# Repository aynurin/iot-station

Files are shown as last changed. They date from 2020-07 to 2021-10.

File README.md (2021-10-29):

# Nour Eggboard

This is a main board of a low-power battery powered IoT device controller based on ESP8266 (ESP-WROOM-02) that drives peripheral devices on I2C bus.

Currenly the project is under development and you can help in the following way:

* Suggest new features and report bugs
* Submit pull requests
* Help fund the development by [donating via PayPal](https://www.paypal.com/donate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)

## LICENSE

Currently this project is licensed as  [GNU AGPLv3](./LICENSE). This is intended to be changed to Apache or MIT when I get a better feel of the project and see how it moves forward. I would accept suggestions of a qualified lawyer as I need help figuring out how to move forward.

## How is this helpful

Most prototyping boards are exactly what they say - designed for prototyping and difficult to apply in a production device or if you are a hardcore hobbyist. Unlike those projects, the Eggboard is intended to be a final solution that lets you hook your peripherals to an I2C bus and enjoy a low-power battery operation, wireless charging, and WiFi connectivity out of the box.

Features:

* WiFi capability via ESP8266
* Own I2C port that allows I2C communication, sleep power line, ability to operate when host sleeps, and a host wakeup channel
* Customizable (via resistance change) sleep timer that drives the host and all of the peripherals
* Battery operation
* Wireless and USB-C charging
* USB-C programming via esptool or Arduino IDE (and other compatible IDEs and methods)

## Nour Egg Plant station

The example implementation is a Nour Egg plant ecosystem controller that is under development. This device is going to be commercially available for purchase in 2022 along with free downloadable app and a cloud-based analytics platform.

Key features of the Nour Egg:

* Monitor air quality, soil moisture, and lighting conditions of your home plant
* Low-power operation that runs for months on a single charge, and wireless charging
* WiFi connectivity to report statistics to the cloud and Nour Egg app
* Appealing look and feel in a nice shell and beautiful RGB light indicators

Implemented peripherals:

* Soil moisture sensor based on capacitance sensing using a coplanar capacitor probe
* Air quality sensor
* Light sensor
* LED indicators board driving 18 leds or 6 RGB leds

## Roadmap

The versioning works by bird names, e.g. see [WhatBird.com NA Birds by Size](https://www.whatbird.com/browse/attribute/birds_na_147/51/Size/):

| Milestone | Release Date | Focus |
|---|---|---|
| [Pine Siskin](https://github.com/aynurin/iot-station/milestone/1) | September 2021 | Hardware design |
| [Pygmy Nuthatch](https://github.com/aynurin/iot-station/milestone/2) | December 2021 | PoC Cloud and App |
| [Winter Wren](https://github.com/aynurin/iot-station/milestone/3) | March 2022 | Production feasible enclosure |
| [Hutton's Vireo](https://github.com/aynurin/iot-station/milestone/4) | June 2022 | Production feasible hardware, test board production |
.

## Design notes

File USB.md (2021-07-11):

|| CP2102N Pin || Description || Manual Section ||
|---|---|---|
| RTS (O) | Ready to Send, Active Low, CP2102N shows that it's ready to receive data | 4.3.7 |
| CTS (I) | Clear to Send, Active Low, External device tells CP2102N that it's ready to receive data | 4.3.7 |
| DSR (I) | Data Set Ready, Active Low | 4.3.11 |
| DTR (O) | Data Terminal Ready, Active Low (May toggle when opening a COM port on some OS'es) | 4.3.11 |
| DCD (I) | Data Carreir Detect, Active Low | 4.3.11 |
| RI (I) | Ring Indicator, Active Low | 4.3.11 |

|| ESP8266 Pin || Description || Manual Section ||
|---|---|---|
| RST | External reset, active low | 0a-esp8266ex_datasheet_en Pin Definitions |
| GPIO0 | UART Download - pull down, Flash boot - floating or pull up | esp8266_quick_start_guide_en #5 |

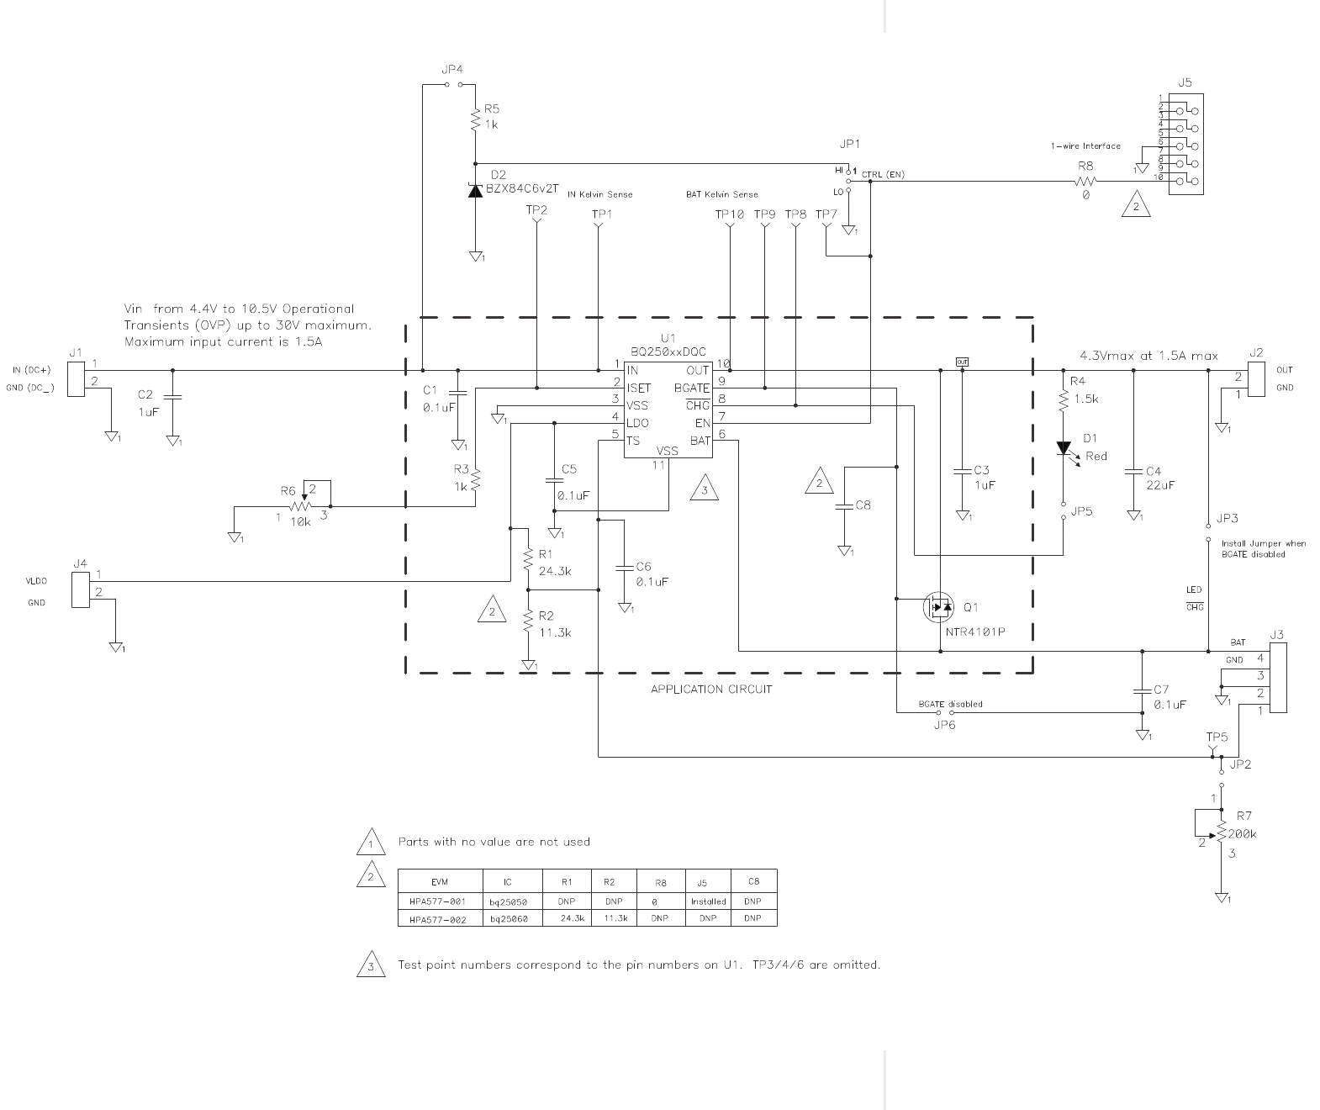
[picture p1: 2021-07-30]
datasheets/bq25050 evl schematics.png

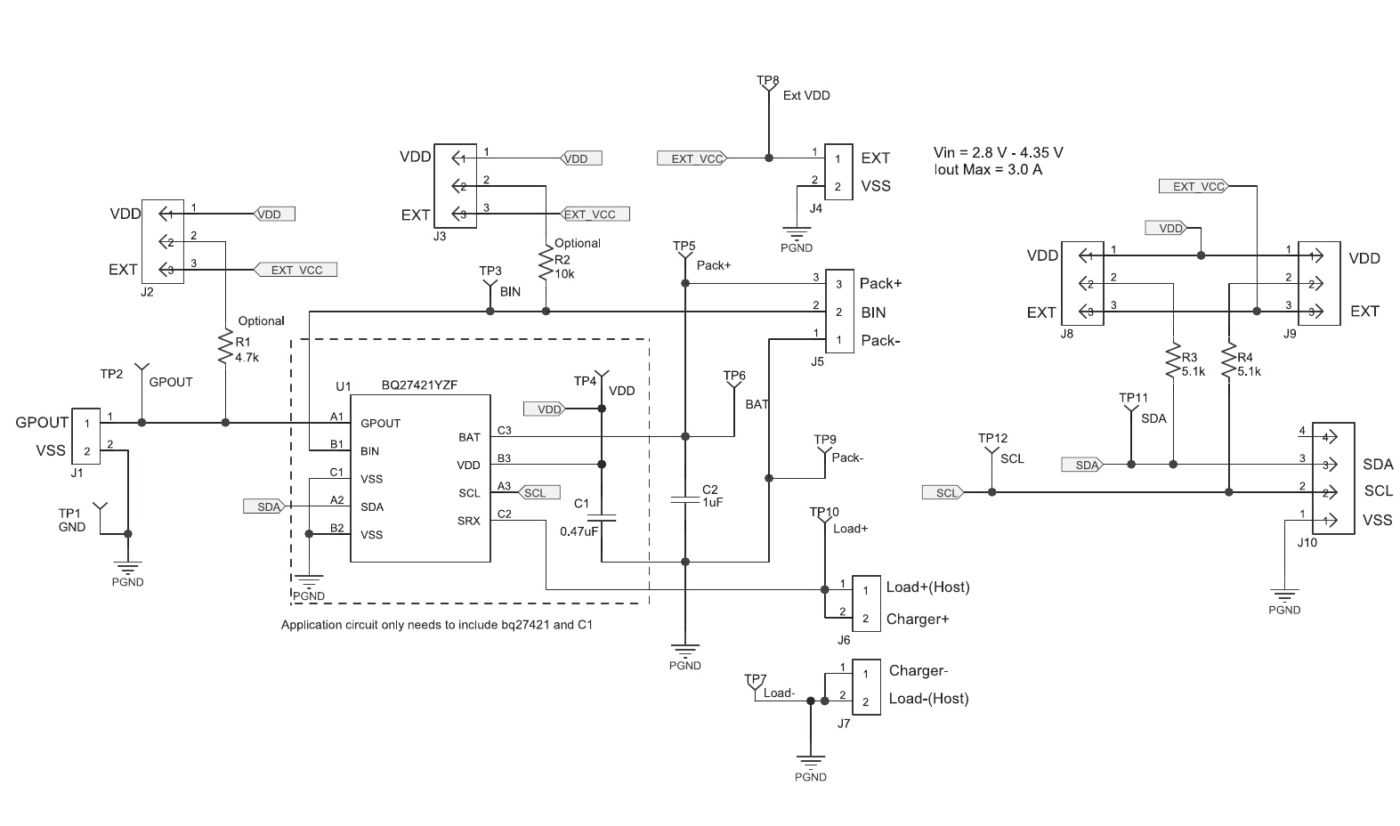
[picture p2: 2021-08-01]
datasheets/bq27421-g1-example-schematics.png

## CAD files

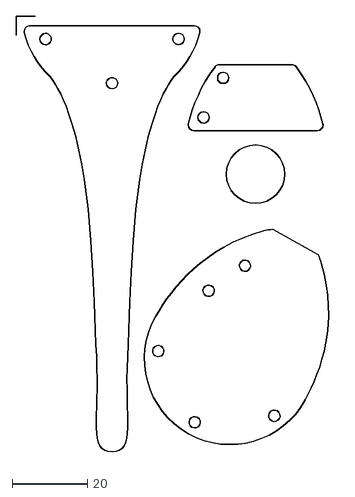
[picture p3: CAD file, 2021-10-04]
assets/board_edge_cuts.dxf
85.6 x 116.9

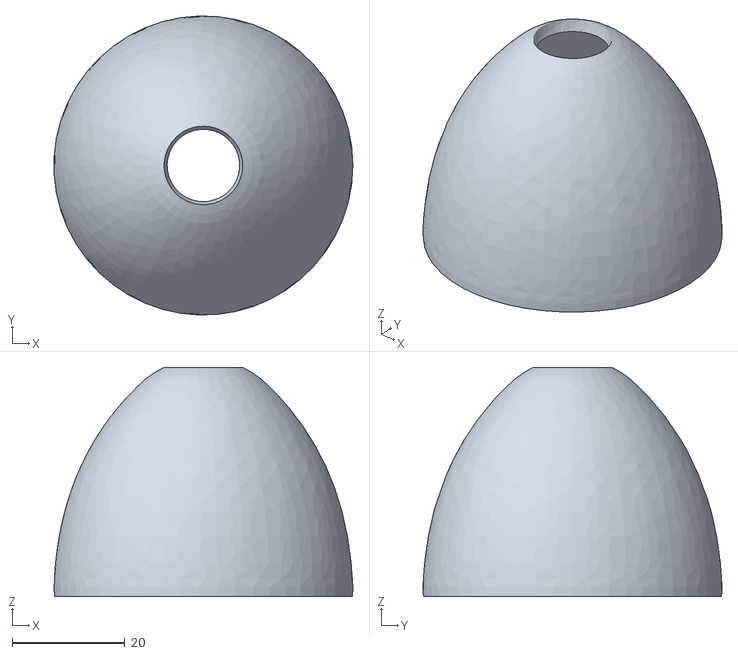
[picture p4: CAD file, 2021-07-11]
assets/enclosure-top.stl
53.1 x 53.1 x 40.7

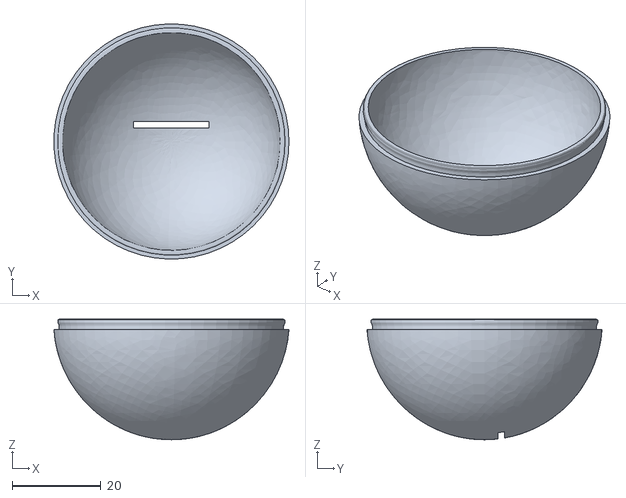
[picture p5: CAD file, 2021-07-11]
assets/enclosure-bottom.stl
52.9 x 52.9 x 27.1

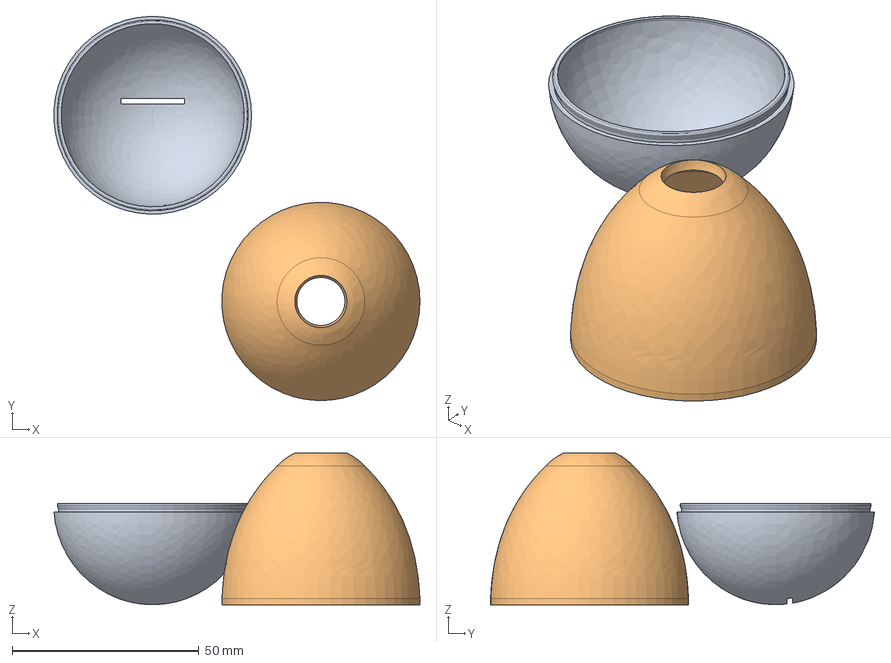
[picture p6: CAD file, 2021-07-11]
assets/enclosure_freecad.FCStd
98.0 x 102.9 x 40.7 mm
Cut001 (Solid)
Cut (Solid)

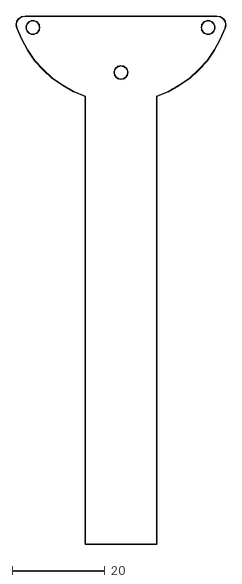
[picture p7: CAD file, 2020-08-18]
assets/moisture_edge_cuts.dxf
45.1 x 113.7

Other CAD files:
assets/enclosure.blend

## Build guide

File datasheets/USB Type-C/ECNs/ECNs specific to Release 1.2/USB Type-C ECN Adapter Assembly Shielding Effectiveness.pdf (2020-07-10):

# USB Type-C ENGINEERING CHANGE NOTICE

USB Implementers Forum | Form 20140811-ECN | Page: 1

# Title: Adapter Assembly Shielding Effectiveness Applied to: USB Type-C Cable and Connector Specification Release 1.2, March 25th, 2016

Brief description of the functional changes proposed:
The change proposed to the specification is the addition of a shielding effectiveness requirement for USB Type-C to USB 3.1 Standard-A Receptacle Adapter Assemblies.

Benefits as a result of the proposed changes:
As the result of this change, well designed adaptor assemblies can be differentiated from poorly-designed adaptor assemblies by comparison against the shielding effectiveness specification.

An assessment of the impact to the existing revision and systems that currently conform to the USB specification:
There may be several USB Type-C to USB 3.1 Standard-A Receptacle Adapter Assemblies that have poor cable shielding and do not meet the shielding effectiveness specification.

An analysis of the hardware implications:
N/A

An analysis of the software implications:
N/A

An analysis of the compliance testing implications:
Measurement was done to evaluate the proposed change using compliance test fixture.

# Actual Change Requested

## (a). Section 3.7.6, Page 97 From Figure 3-56

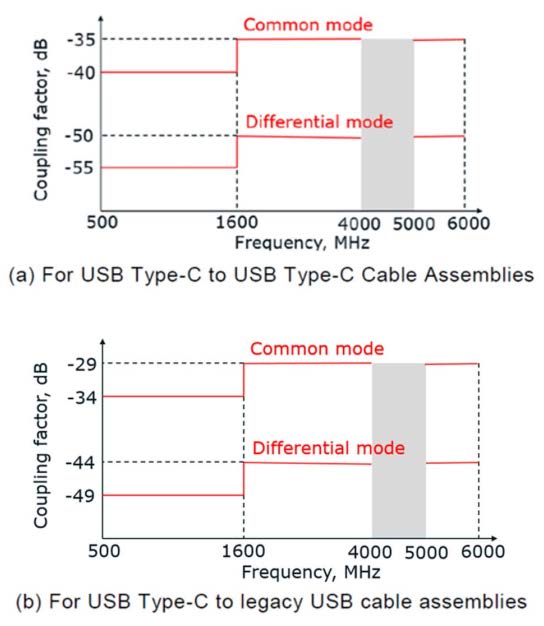
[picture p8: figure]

## To Figure 3-56:

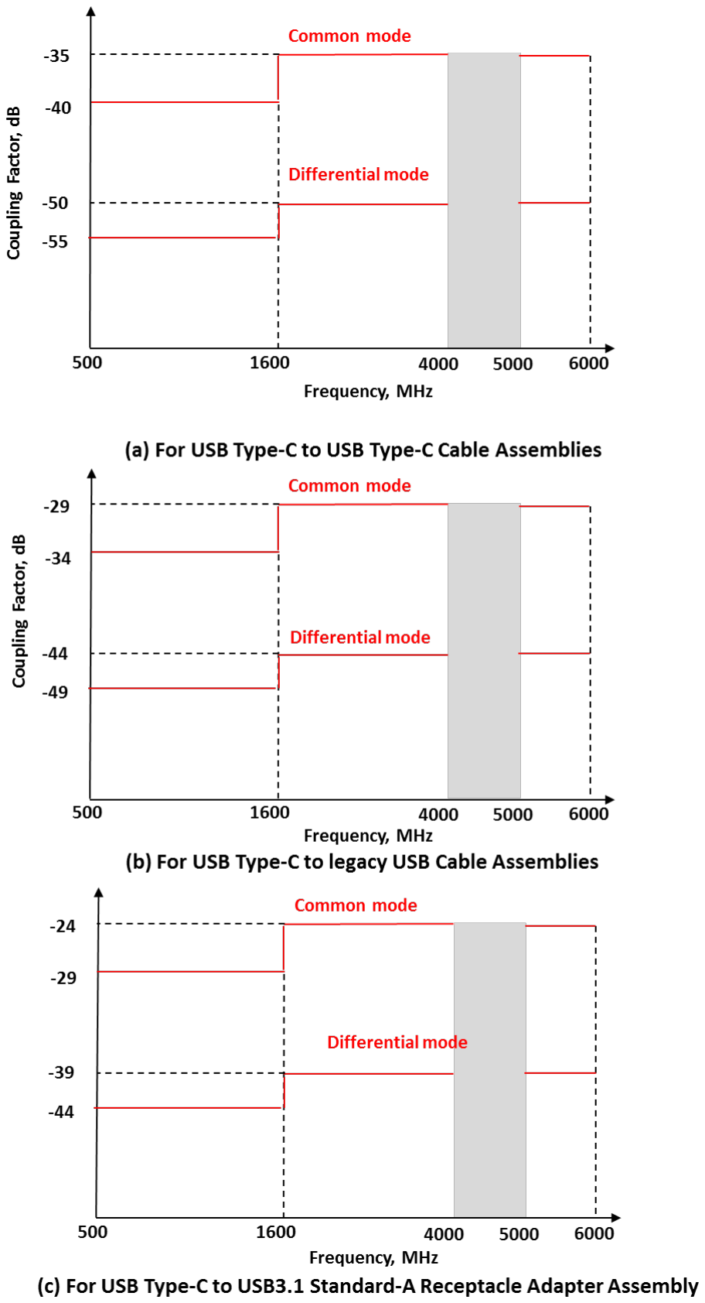
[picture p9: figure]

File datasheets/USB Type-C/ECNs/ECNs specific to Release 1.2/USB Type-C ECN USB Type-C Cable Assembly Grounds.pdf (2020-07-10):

USB Type-C ENGINEERING CHANGE NOTICE

USB Implementers Forum | Form 12022008 | Page: | 1

Title: USB Type-C Cable Assembly Grounding
Applied to: USB Type-C Specification Release 1.2

Brief description of the functional changes proposed:
This ECN requires that all grounds and shields are made common within the standard USB Type-C and USB Type-C to legacy cable assemblies.

Benefits as a result of the proposed changes:
Currently it is allowable to isolate shell and signal grounds within a USB Type-C cable assembly. Cable assemblies with common grounds and isolated grounds require different compliance test methods/fixtures for IR drop measurement. This adds complexity and the potential for failure escapes. Finished product testing should also be tested with both types of ground connection cables to ensure compliance with product emissions.

An assessment of the impact to the existing revision and systems that currently conform to the USB specification:
No impact to existing systems.

An analysis of the hardware implications:
Cable assembly suppliers continue to have flexibility in design, construction, and materials to meet the IR drop spec. However, the ECN unifies the measured path by mandating that if separate ground paths are present that they be made common. This also eliminates the need for emissions testing at the product level using both isolated shield and grounded shield cable assemblies.

An analysis of the software implications:
NA

An analysis of the compliance testing implications:
No change to current compliance testing requirements. Reduces chance of failure escapes.

USB Implementers Forum | Form 12022008 | Page: | 2

Actual Change Requested

From Text (and location): Section 3.4.1, Table 3-10

Table 3-1 USB Full-Featured Type-C Standard Cable Assembly Wiring

USB Type-C Plug #1 | Wire | USB Type-C Plug #2
Pin | Signal Name | Wire Number | Signal Name | Pin | Signal Name
A1, B1, A12, B12 | GND | 1 [16] | GND_PWRrt1 [GND_PWRrt2] | A1, B1, A12, B12 | GND
A4, B4, A9, B9 | VBUS | 2 [17] | PWR_VBUS1 [PWR_VBUS2] | A4, B4, A9, B9 | VBUS
A5 | CC | 3 | CC | A5 | CC
B5 | VCONN | 18 | PWR_VCONN (See Section 4.9) | B5 | VCONN
A6 | Dp1 | 4 | UTP_Dp | A6 | Dp1
A7 | Dn1 | 5 | UTP_Dn | A7 | Dn1
A2 | SSTXp1 | 6 | SDPp1 | B11 | SSRXp1
A3 | SSTXn1 | 7 | SDPn1 | B10 | SSRXn1
B11 | SSRXp1 | 8 | SDPp2 | A2 | SSTXp1
B10 | SSRXn1 | 9 | SDPn2 | A3 | SSTXn1
B2 | SSTXp2 | 10 | SDPp3 | A11 | SSRXp2
B3 | SSTXn2 | 11 | SDPn3 | A10 | SSRXn2
A11 | SSRXp2 | 12 | SDPp4 | B2 | SSTXp2
A10 | SSRXn2 | 13 | SDPn4 | B3 | SSTXn2
A8 | SBU1 | 14 | SBU_A | B8 | SBU2
B8 | SBU2 | 15 | SBU_B | A8 | SBU1
Shell | Shield | Braid | Shield | Shell | Shield
Notes:
1. This table is based on the assumption that coaxial wire construction is used for all SDP’s and there are no drain wires. The shields of the coaxial wires are connected to the ground pins. If shielded twisted pair is used, then drain wires are needed and shall be connected to the GND pins.
2. Pin B5 (VCONN) of the USB Type-C plug shall be used in electronically marked versions of this cable. See Section 4.9.
3. Contacts B6 and B7 should not be present in the USB Type-C plug.
4. All VBUS pins shall be connected together within the USB Type-C plug. A 10 nF bypass capacitor (minimum voltage rating of 30 V) is required for the VBUS pin in the full-featured cable at each end of the cable. The bypass capacitor should be placed as close as possible to the power supply pad.
5. All GND pins shall be connected together within the USB Type-C plug.

USB Implementers Forum | Form 12022008 | Page: | 3

To Text (and location): Section 3.4.1, Table 3-10

Table 3-2 USB Full-Featured Type-C Standard Cable Assembly Wiring

USB Type-C Plug #1 | Wire | USB Type-C Plug #2
Pin | Signal Name | Wire Number | Signal Name | Pin | Signal Name
A1, B1, A12, B12 | GND | 1 [16] | GND_PWRrt1 [GND_PWRrt2] | A1, B1, A12, B12 | GND
A4, B4, A9, B9 | VBUS | 2 [17] | PWR_VBUS1 [PWR_VBUS2] | A4, B4, A9, B9 | VBUS
A5 | CC | 3 | CC | A5 | CC
B5 | VCONN | 18 | PWR_VCONN (See Section 4.9) | B5 | VCONN
A6 | Dp1 | 4 | UTP_Dp | A6 | Dp1
A7 | Dn1 | 5 | UTP_Dn | A7 | Dn1
A2 | SSTXp1 | 6 | SDPp1 | B11 | SSRXp1
A3 | SSTXn1 | 7 | SDPn1 | B10 | SSRXn1
B11 | SSRXp1 | 8 | SDPp2 | A2 | SSTXp1
B10 | SSRXn1 | 9 | SDPn2 | A3 | SSTXn1
B2 | SSTXp2 | 10 | SDPp3 | A11 | SSRXp2
B3 | SSTXn2 | 11 | SDPn3 | A10 | SSRXn2
A11 | SSRXp2 | 12 | SDPp4 | B2 | SSTXp2
A10 | SSRXn2 | 13 | SDPn4 | B3 | SSTXn2
A8 | SBU1 | 14 | SBU_A | B8 | SBU2
B8 | SBU2 | 15 | SBU_B | A8 | SBU1
Shell | Shield | Outer shield | Shield | Shell | Shield

Notes:

1. This table is based on the assumption that coaxial wire construction is used for all SDP’s and there are no drain wires. The shields of the coaxial wires are connected to the ground pins. If shielded twisted pair is used, then drain wires are needed and shall be connected to the GND pins.
2. Pin B5 (VCONN) of the USB Type-C plug shall be used in electronically marked versions of this cable. See Section 4.9.
3. Contacts B6 and B7 should not be present in the USB Type-C plug.
4. All VBUS pins shall be connected together within the USB Type-C plug. A 10 nF bypass capacitor (minimum voltage rating of 30 V) is required for the VBUS pin in the full-featured cable at each end of the cable. The bypass capacitor should be placed as close as possible to the power supply pad.
5. All GND pins shall be connected together within the USB Type-C plug.
6. Shield and GND shall be connected within the USB Type-C plug on both ends of the cable assembly.

USB Implementers Forum | Form 12022008 | Page: | 4

Actual Change Requested

From Text (and location): Section 3.4.2, Table 3-11

Table 3-3 USB 2.0 Type-C Standard Cable Assembly Wiring

USB Type-C Plug #1 | Wire | USB Type-C Plug #2
Pin | Signal Name | Wire Number | Signal Name | Pin | Signal Name
A1, B1, A12, B12 | GND | 1 | GND_PWRrt1 | A1, B1, A12, B12 | GND
A4, B4, A9, B9 | VBUS | 2 | PWR_VBUS1 | A4, B4, A9, B9 | VBUS
A5 | CC | 3 | CC | A5 | CC
B5 | VCONN | 18 | PWR_VCONN (See Section 4.9) | B5 | VCONN
A6 | Dp1 | 4 | UTP_Dp | A6 | Dp1
A7 | Dn1 | 5 | UTP_Dn | A7 | Dn1
Shell | Shield | Braid | Shield | Shell | Shield
Notes:
1. Pin B5 (VCONN) of the USB Type-C plug shall be used in electronically marked versions of this cable. See Section 4.9.
2. Contacts B6 and B7 should not be present in the USB Type-C plug.
3. All VBUS pins shall be connected together within the USB Type-C plug. A bypass capacitor is not required for the VBUS pin in the USB 2.0 Type-C cable.
4. All GND pins shall be connected together within the USB Type-C plug.
5. All USB Type-C plug pins that are not listed in this table shall be open (not connected).

To Text (and location): Section 3.4.2, Table 3-11

USB Implementers Forum | Form 12022008 | Page: | 5

Table 3-4 USB 2.0 Type-C Standard Cable Assembly Wiring

USB Type-C Plug #1 | Wire | USB Type-C Plug #2
Pin | Signal Name | Wire Number | Signal Name | Pin | Signal Name
A1, B1, A12, B12 | GND | 1 | GND_PWRrt1 | A1, B1, A12, B12 | GND
A4, B4, A9, B9 | VBUS | 2 | PWR_VBUS1 | A4, B4, A9, B9 | VBUS
A5 | CC | 3 | CC | A5 | CC
B5 | VCONN | 18 | PWR_VCONN (See Section 4.9) | B5 | VCONN
A6 | Dp1 | 4 | UTP_Dp | A6 | Dp1
A7 | Dn1 | 5 | UTP_Dn | A7 | Dn1
Shell | Shield | Outer shield | Shield | Shell | Shield

Notes:

1. Pin B5 (VCONN) of the USB Type-C plug shall be used in electronically marked versions of this cable. See Section 4.9.
2. Contacts B6 and B7 should not be present in the USB Type-C plug.
3. All VBUS pins shall be connected together within the USB Type-C plug. A bypass capacitor is not required for the VBUS pin in the USB 2.0 Type-C cable.
4. All GND pins shall be connected together within the USB Type-C plug.
5. All USB Type-C plug pins that are not listed in this table shall be open (not connected).
6. Shield and GND grounds shall be connected within the USB Type-C plug on both ends of the cable assembly.

USB Implementers Forum | Form 12022008 | Page: | 6

Actual Change Requested

From Text (and location): Section 3.5.1, Table 3-12

Table 3-5 USB Type-C to USB 3.1 Standard-A Cable Assembly Wiring

USB Type-C Plug | Wire | USB 3.1 Standard-A plug
Pin | Signal Name | Wire Number | Signal Name | Pin | Signal Name
A1, B1, A12, B12 | GND | 1 7, 10 | GND_PWRrt1 SDP1_Drain, SDP2_Drain | 4 7 | GND GND_DRAIN
A4, B4, A9, B9 | VBUS | 2 | PWR_VBUS1 | 1 | VBUS
A5 | CC
B5 | VCONN
A6 | Dp1 | 3 | UTP_Dp | 3 | D+
A7 | Dn1 | 4 | UTP_Dn | 2 | D−
A2 | SSTXp1 | 5 | SDPp1 | 6 | StdA_SSRX+
A3 | SSTXn1 | 6 | SDPn1 | 5 | StdA_SSRX−
B11 | SSRXp1 | 8 | SDPp2 | 9 | StdA_SSTX+
B10 | SSRXn1 | 9 | SDPn2 | 8 | StdA_SSTX−
Shell | Shield | Braid | Shield | Shell | Shield
Notes:
1. This table is based on the assumption that shielded twisted pair is used for all SDP’s and there are drain wires. If coaxial wire construction is used, then no drain wires are present and the shields of the coaxial wires are connected to the ground pins.
2. Pin A5 (CC) of the USB Type-C plug shall be connected to VBUS through a resistor Rp. See Section 4.5.3.2.2 and Table 4-13 for the functional description and value of Rp.
3. Pin B5 (VCONN) of the USB Type-C plug shall be used in electronically marked versions of this cable. See Section 4.9.
4. Contacts B6 and B7 should not be present in the USB Type-C plug.
5. All VBUS pins shall be connected together within the USB Type-C plug. A bypass capacitor is required between the VBUS and ground pins in the USB Type-C plug side of the cable. The bypass capacitor shall be 10nF ± 20% in cables which incorporate a USB Standard-A plug. The bypass capacitor shall be 100pF ± 20% (minimum voltage rating of 30V) in cables which incorporate a USB PD Standard-A plug. The bypass capacitor shall be placed as close as possible to the power supply
pad.
6. All Ground return pins shall be connected together within the USB Type-C plug.
7. All USB Type-C plug pins that are not listed in this table shall be open (not connected).

USB Implementers Forum | Form 12022008 | Page: | 7

To Text (and location): Section 3.5.1, Table 3-12

Table 3-6 USB Type-C to USB 3.1 Standard-A Cable Assembly Wiring

USB Type-C Plug | Wire | USB 3.1 Standard-A plug
Pin | Signal Name | Wire Number | Signal Name | Pin | Signal Name
A1, B1, A12, B12 | GND | 1 7, 10 | GND_PWRrt1 SDP1_Drain, SDP2_Drain | 4 7 | GND GND_DRAIN
A4, B4, A9, B9 | VBUS | 2 | PWR_VBUS1 | 1 | VBUS
A5 | CC
B5 | VCONN
A6 | Dp1 | 3 | UTP_Dp | 3 | D+
A7 | Dn1 | 4 | UTP_Dn | 2 | D−
A2 | SSTXp1 | 5 | SDPp1 | 6 | StdA_SSRX+
A3 | SSTXn1 | 6 | SDPn1 | 5 | StdA_SSRX−
B11 | SSRXp1 | 8 | SDPp2 | 9 | StdA_SSTX+
B10 | SSRXn1 | 9 | SDPn2 | 8 | StdA_SSTX−
Shell | Shield | Outer shield | Shield | Shell | Shield

Notes:

1. This table is based on the assumption that shielded twisted pair is used for all SDP’s and there are drain wires. If coaxial wire construction is used, then no drain wires are present and the shields of the coaxial wires are connected to the ground pins.
2. Pin A5 (CC) of the USB Type-C plug shall be connected to VBUS through a resistor Rp. See Section 4.5.3.2.2 and Table 4-13 for the functional description and value of Rp.
3. Pin B5 (VCONN) of the USB Type-C plug shall be used in electronically marked versions of this cable. See Section 4.9.
4. Contacts B6 and B7 should not be present in the USB Type-C plug.
5. All VBUS pins shall be connected together within the USB Type-C plug. A bypass capacitor is required between the VBUS and ground pins in the USB Type-C plug side of the cable. The bypass capacitor shall be 10nF ± 20% in cables which incorporate a USB Standard-A plug. The bypass capacitor shall be 100pF ± 20% (minimum voltage rating of 30V) in cables which incorporate a USB PD Standard-A plug. The bypass capacitor shall be placed as close as possible to the power supply
pad.
6. All Ground return pins shall be connected together within the USB Type-C plug.
7. Shield and GND grounds shall be connected within the USB Type-C and USB 3.1 Standard-A plugs on both ends of the cable assembly.
8. All USB Type-C plug pins that are not listed in this table shall be open (not connected).

USB Implementers Forum | Form 12022008 | Page: | 8

Actual Change Requested

From Text (and location): Section 3.5.2, Table 3-13

Table 3-7 USB Type-C to USB 2.0 Standard-A Cable Assembly Wiring

USB Type-C Plug | Wire | USB 2.0 Standard-A plug
Pin | Signal Name | Wire Number | Signal Name | Pin | Signal Name
A1, B1, A12, B12 | GND | 1 | GND_PWRrt1 | 4 | GND
A4, B4, A9, B9 | VBUS | 2 | PWR_VBUS1 | 1 | VBUS
A5 | CC
B5 | VCONN
A6 | Dp1 | 3 | UTP_Dp | 3 | D+
A7 | Dn1 | 4 | UTP_Dn | 2 | D−
Shell | Shield | Braid | Shield | Shell | Shield
Notes:
1. Pin A5 (CC) of the USB Type-C plug shall be connected to VBUS through a resistor Rp. See Section 4.5.3.2.2 and Table 4-13 for the functional description and value of Rp.
2. Pin B5 (VCONN) of the USB Type-C plug shall be used in electronically marked versions of this cable. See Section 4.9.
3. Contacts B6 and B7 should not be present in the USB Type-C plug.
4. All VBUS pins shall be connected together within the USB Type-C plug. Bypass capacitors are not required for the VBUS pins in this cable.
5. All Ground return pins shall be connected together within the USB Type-C plug.
6. All USB Type-C plug pins that are not listed in this table shall be open (not connected).

USB Implementers Forum | Form 12022008 | Page: | 9

To Text (and location): Section 3.5.2, Table 3-13

Table 3-8 USB Type-C to USB 2.0 Standard-A Cable Assembly Wiring

USB Type-C Plug | Wire | USB 2.0 Standard-A plug
Pin | Signal Name | Wire Number | Signal Name | Pin | Signal Name
A1, B1, A12, B12 | GND | 1 | GND_PWRrt1 | 4 | GND
A4, B4, A9, B9 | VBUS | 2 | PWR_VBUS1 | 1 | VBUS
A5 | CC
B5 | VCONN
A6 | Dp1 | 3 | UTP_Dp | 3 | D+
A7 | Dn1 | 4 | UTP_Dn | 2 | D−
Shell | Shield | Outer shield | Shield | Shell | Shield

Notes:

1. Pin A5 (CC) of the USB Type-C plug shall be connected to VBUS through a resistor Rp. See Section 4.5.3.2.2 and Table 4-13 for the functional description and value of Rp.
2. Pin B5 (VCONN) of the USB Type-C plug shall be used in electronically marked versions of this cable. See Section 4.9.
3. Contacts B6 and B7 should not be present in the USB Type-C plug.
4. All VBUS pins shall be connected together within the USB Type-C plug. Bypass capacitors are not required for the VBUS pins in this cable.
5. All Ground return pins shall be connected together within the USB Type-C plug.
6. Shield and GND grounds shall be connected within the USB Type-C and USB 2.0 Standard-A plugs on both ends of the cable assembly.
7. All USB Type-C plug pins that are not listed in this table shall be open (not connected).

USB Implementers Forum | Form 12022008 | Page: 10

Actual Change Requested

From Text (and location): Section 3.5.3, Table 3-14

Table 3-9 USB Type-C to USB 3.1 Standard-B Cable Assembly Wiring

USB Type-C Plug | Wire | USB 3.1 Standard-B plug
Pin | Signal Name | Wire Number | Signal Name | Pin | Signal Name
A1, B1, A12, B12 | GND | 1 7, 10 | GND_PWRrt1 SDP1_Drain, SDP2_Drain | 4 7 | GND GND_DRAIN
A4, B4, A9, B9 | VBUS | 2 | PWR_VBUS1 | 1 | VBUS
A5 | CC
B5 | VCONN
A6 | Dp1 | 3 | UTP_Dp | 3 | D+
A7 | Dn1 | 4 | UTP_Dn | 2 | D−
A2 | SSTXp1 | 5 | SDPp1 | 9 | StdB_SSRX+
A3 | SSTXn1 | 6 | SDPn1 | 8 | StdB_SSRX−
B11 | SSRXp1 | 8 | SDPp2 | 6 | StdB_SSTX+
B10 | SSRXn1 | 9 | SDPn2 | 5 | StdB_SSTX−
Shell | Shield | Braid | Shield | Shell | Shield
Notes:
1. Pin A5 (CC) of the USB Type-C plug shall be connected to GND through a resistor Rd. See Section 4.5.3.2.1 and Table 4-14 for the functional description and value of Rd.
2. Pin B5 (VCONN) of the USB Type-C plug shall be used in electronically marked versions of this cable. See Section 4.9.
3. This table is based on the assumption that shielded twisted pair is used for all SDP’s and there are drain wires. If coaxial wire construction is used, then no drain wires are present and the shields of the coaxial wires are connected to the ground pins.
4. Contacts B6 and B7 should not be present in the USB Type-C plug.
5. All VBUS pins shall be connected together within the USB Type-C plug. A bypass capacitor is required between the VBUS and ground pins in the USB Type-C plug side of the cable. The bypass capacitor shall be 10nF ± 20% in cables which incorporate a USB Standard-B plug. The bypass capacitor shall be 100pF ± 20% (minimum voltage rating of 30V) in cables which incorporate a USB PD Standard-B plug. The bypass capacitor shall be placed as close as possible to the power supply
pad.
6. All Ground return pins shall be connected together within the USB Type-C plug.
7. All USB Type-C plug pins that are not listed in this table shall be open (not connected).

To Text (and location): Section 3.5.3, Table 3-14

Table 3-10 USB Type-C to USB 3.1 Standard-B Cable Assembly Wiring

USB Type-C Plug | Wire | USB 3.1 Standard-B plug
Pin | Signal Name | Wire Number | Signal Name | Pin | Signal Name
A1, B1, A12, B12 | GND | 1 7, 10 | GND_PWRrt1 SDP1_Drain, SDP2_Drain | 4 7 | GND GND_DRAIN
A4, B4, A9, B9 | VBUS | 2 | PWR_VBUS1 | 1 | VBUS
A5 | CC
B5 | VCONN
A6 | Dp1 | 3 | UTP_Dp | 3 | D+
A7 | Dn1 | 4 | UTP_Dn | 2 | D−
A2 | SSTXp1 | 5 | SDPp1 | 9 | StdB_SSRX+
A3 | SSTXn1 | 6 | SDPn1 | 8 | StdB_SSRX−
B11 | SSRXp1 | 8 | SDPp2 | 6 | StdB_SSTX+
B10 | SSRXn1 | 9 | SDPn2 | 5 | StdB_SSTX−
Shell | Shield | Outer shield | Shield | Shell | Shield

Notes:

1. Pin A5 (CC) of the USB Type-C plug shall be connected to GND through a resistor Rd. See Section 4.5.3.2.1 and Table 4-14 for the functional description and value of Rd.
2. Pin B5 (VCONN) of the USB Type-C plug shall be used in electronically marked versions of this cable. See Section 4.9.
3. This table is based on the assumption that shielded twisted pair is used for all SDP’s and there are drain wires. If coaxial wire construction is used, then no drain wires are present and the shields of the coaxial wires are connected to the ground pins.
4. Contacts B6 and B7 should not be present in the USB Type-C plug.
5. All VBUS pins shall be connected together within the USB Type-C plug. A bypass capacitor is required between the VBUS and ground pins in the USB Type-C plug side of the cable. The bypass capacitor shall be 10nF ± 20% in cables which incorporate a USB Standard-B plug. The bypass capacitor shall be 100pF ± 20% (minimum voltage rating of 30V) in cables which incorporate a USB PD Standard-B plug. The bypass capacitor shall be placed as close as possible to the power supply
pad.
6. All Ground return pins shall be connected together within the USB Type-C plug.
7. Shield and GND grounds shall be connected within the USB Type-C and USB 3.1 Standard-B plugs on both ends of the cable assembly.
8. All USB Type-C plug pins that are not listed in this table shall be open (not connected).

Actual Change Requested

From Text (and location): Section 3.5.4, Table 3-15

Table 3-11 USB Type-C to USB 2.0 Standard-B Cable Assembly Wiring

USB Type-C Plug | Wire | USB 2.0 Standard-B plug
Pin | Signal Name | Wire Number | Signal Name | Pin | Signal Name
A1, B1, A12, B12 | GND | 1 | GND_PWRrt1 | 4 | GND
A4, B4, A9, B9 | VBUS | 2 | PWR_VBUS1 | 1 | VBUS
A5 | CC
B5 | VCONN
A6 | Dp1 | 3 | UTP_Dp | 3 | D+
A7 | Dn1 | 4 | UTP_Dn | 2 | D−
Shell | Shield | Braid | Shield | Shell | Shield
Notes:
1. Pin A5 (CC) of the USB Type-C plug shall be connected to GND through a resistor Rd. See Section 4.5.3.2.1 and Table 4-14 for the functional description and value of Rd.
2. Pin B5 (VCONN) of the USB Type-C plug shall be used in electronically marked versions of this cable. See Section 4.9.
3. Contacts B6 and B7 should not be present in the USB Type-C plug.
4. All VBUS pins shall be connected together within the USB Type-C plug. Bypass capacitors are not required for the VBUS pins in this cable.
5. All Ground return pins shall be connected together within the USB Type-C plug.
6. All USB Type-C plug pins that are not listed in this table shall be open (not connected).

To Text (and location): Section 3.5.4, Table 3-15

Table 3-12 USB Type-C to USB 2.0 Standard-B Cable Assembly Wiring

USB Type-C Plug | Wire | USB 2.0 Standard-B plug
Pin | Signal Name | Wire Number | Signal Name | Pin | Signal Name
A1, B1, A12, B12 | GND | 1 | GND_PWRrt1 | 4 | GND
A4, B4, A9, B9 | VBUS | 2 | PWR_VBUS1 | 1 | VBUS
A5 | CC
B5 | VCONN
A6 | Dp1 | 3 | UTP_Dp | 3 | D+
A7 | Dn1 | 4 | UTP_Dn | 2 | D−
Shell | Shield | Outer shield | Shield | Shell | Shield

Notes:

1. Pin A5 (CC) of the USB Type-C plug shall be connected to GND through a resistor Rd. See Section 4.5.3.2.1 and Table 4-14 for the functional description and value of Rd.
2. Pin B5 (VCONN) of the USB Type-C plug shall be used in electronically marked versions of this cable. See Section 4.9.
3. Contacts B6 and B7 should not be present in the USB Type-C plug.
4. All VBUS pins shall be connected together within the USB Type-C plug. Bypass capacitors are not required for the VBUS pins in this cable.
5. All Ground return pins shall be connected together within the USB Type-C plug.
6. Shield and GND grounds shall be connected within the USB Type-C and USB 2.0 Standard-B plugs on both ends of the cable assembly.
7. All USB Type-C plug pins that are not listed in this table shall be open (not connected).

Actual Change Requested

From Text (and location): Section 3.5.5, Table 3-16

Table 3-13 USB Type-C to USB 2.0 Mini-B Cable Assembly Wiring

USB Type-C Plug | Wire | USB 2.0 Mini-B plug
Pin | Signal Name | Wire Number | Signal Name | Pin | Signal Name
A1, B1, A12, B12 | GND | 1 | GND_PWRrt1 | 5 | GND
A4, B4, A9, B9 | VBUS | 2 | PWR_VBUS1 | 1 | VBUS
A5 | CC
A6 | Dp1 | 3 | UTP_Dp | 3 | D+
A7 | Dn1 | 4 | UTP_Dn | 2 | D−
| | | | 4 | ID
Shell | Shield | Braid | Shield | Shell | Shield
Notes:
1. Pin A5 of the USB Type-C plug shall be connected to GND through a resistor Rd. See Section 4.5.3.2.1 and Table 4-14 for the functional description and value of Rd.
2. Contacts B6 and B7 should not be present in the USB Type-C plug.
3. All VBUS pins shall be connected together within the USB Type-C plug. Bypass capacitors are not required for the VBUS pins in this cable.
4. All Ground return pins shall be connected together within the USB Type-C plug.
5. Pin 4 (ID) of the USB 2.0 Mini-B plug shall be terminated as defined in the applicable specification for the cable type.
6. All USB Type-C plug pins that are not listed in this table shall be open (not connected).

To Text (and location): Section 3.5.5, Table 3-16

Table 3-14 USB Type-C to USB 2.0 Mini-B Cable Assembly Wiring

USB Type-C Plug | Wire | USB 2.0 Mini-B plug
Pin | Signal Name | Wire Number | Signal Name | Pin | Signal Name
A1, B1, A12, B12 | GND | 1 | GND_PWRrt1 | 5 | GND
A4, B4, A9, B9 | VBUS | 2 | PWR_VBUS1 | 1 | VBUS
A5 | CC
A6 | Dp1 | 3 | UTP_Dp | 3 | D+
A7 | Dn1 | 4 | UTP_Dn | 2 | D−
| | | | 4 | ID
Shell | Shield | Outer shield | Shield | Shell | Shield

Notes:

1. Pin A5 of the USB Type-C plug shall be connected to GND through a resistor Rd. See Section 4.5.3.2.1 and Table 4-14 for the functional description and value of Rd.
2. Contacts B6 and B7 should not be present in the USB Type-C plug.
3. All VBUS pins shall be connected together within the USB Type-C plug. Bypass capacitors are not required for the VBUS pins in this cable.
4. All Ground return pins shall be connected together within the USB Type-C plug.
5. Pin 4 (ID) of the USB 2.0 Mini-B plug shall be terminated as defined in the applicable specification for the cable type.
6. Shield and GND grounds shall be connected within the USB Type-C and USB 2.0 Mini-B plugs on both ends of the cable assembly.
7. All USB Type-C plug pins that are not listed in this table shall be open (not connected).

Actual Change Requested

From Text (and location): Section 3.5.6, Table 3-17

Table 3-15 USB Type-C to USB 3.1 Micro-B Cable Assembly Wiring

USB Type-C Plug | Wire | USB 3.1 Micro-B plug
Pin | Signal Name | Wire Number | Signal Name | Pin | Signal Name
A1, B1, A12, B12 | GND | 1 7, 10 | GND_PWRrt1 SDP1_Drain, SDP2_Drain | 5 8 | GND GND_DRAIN
A4, B4, A9, B9 | VBUS | 2 | PWR_VBUS1 | 1 | VBUS
A5 | CC
B5 | VCONN
A6 | Dp1 | 3 | UTP_Dp | 3 | D+
A7 | Dn1 | 4 | UTP_Dn | 2 | D−
A2 | SSTXp1 | 5 | SDPp1 | 10 | MicB_SSRX+
A3 | SSTXn1 | 6 | SDPn1 | 9 | MicB_SSRX−
B11 | SSRXp1 | 8 | SDPp2 | 7 | MicB_SSTX+
B10 | SSRXn1 | 9 | SDPn2 | 6 | MicB_SSTX−
| | | | 4 | ID
Shell | Shield | Braid | Shield | Shell | Shield
Notes:
1. Pin A5 (CC) of the USB Type-C plug shall be connected to GND through a resistor Rd. See Section 4.5.3.2.1 and Table 4-14 for the functional description and value of Rd.
2. Pin B5 (VCONN) of the USB Type-C plug shall be used in electronically marked versions of this cable. See Section 4.9.
3. This table is based on the assumption that shielded twisted pair is used for all SDP’s and there are drain wires. If coaxial wire construction is used, then no drain wires are present and the shields of the coaxial wires are connected to the ground pins.
4. Contacts B6 and B7 should not be present in the USB Type-C plug.
5. All VBUS pins shall be connected together within the USB Type-C plug. A bypass capacitor is required between the VBUS and ground pins in the USB Type-C plug side of the cable. The bypass capacitor shall be 10nF ± 20% in cables which incorporate a USB Micro-B plug. The bypass capacitor shall be 100pF ± 20% (minimum voltage rating of 30V) in cables which incorporate a USB PD Micro-B plug. The bypass capacitor should be placed as close as possible to the power supply
pad.
6. All Ground return pins shall be connected together within the USB Type-C plug.
7. Pin 4 (ID) of the USB 3.1 Micro-B plug shall be terminated as defined in the applicable specification for the cable type.
8. All USB Type-C plug pins that are not listed in this table shall be open (not connected).

To Text (and location): Section 3.5.6, Table 3-17

Table 3-16 USB Type-C to USB 3.1 Micro-B Cable Assembly Wiring

USB Type-C Plug | Wire | USB 3.1 Micro-B plug

Pin | Signal Name | Wire Number | Signal Name | Pin | Signal Name
A1, B1, A12, B12 | GND | 1 7, 10 | GND_PWRrt1 SDP1_Drain, SDP2_Drain | 5 8 | GND GND_DRAIN
A4, B4, A9, B9 | VBUS | 2 | PWR_VBUS1 | 1 | VBUS
A5 | CC
B5 | VCONN
A6 | Dp1 | 3 | UTP_Dp | 3 | D+
A7 | Dn1 | 4 | UTP_Dn | 2 | D−
A2 | SSTXp1 | 5 | SDPp1 | 10 | MicB_SSRX+
A3 | SSTXn1 | 6 | SDPn1 | 9 | MicB_SSRX−
B11 | SSRXp1 | 8 | SDPp2 | 7 | MicB_SSTX+
B10 | SSRXn1 | 9 | SDPn2 | 6 | MicB_SSTX−
| | | | 4 | ID
Shell | Shield | Outer shield | Shield | Shell | Shield

Notes:

1. Pin A5 (CC) of the USB Type-C plug shall be connected to GND through a resistor Rd. See Section 4.5.3.2.1 and Table 4-14 for the functional description and value of Rd.
2. Pin B5 (VCONN) of the USB Type-C plug shall be used in electronically marked versions of this cable. See Section 4.9.
3. This table is based on the assumption that shielded twisted pair is used for all SDP’s and there are drain wires. If coaxial wire construction is used, then no drain wires are present and the shields of the coaxial wires are connected to the ground pins.
4. Contacts B6 and B7 should not be present in the USB Type-C plug.
5. All VBUS pins shall be connected together within the USB Type-C plug. A bypass capacitor is required between the VBUS and ground pins in the USB Type-C plug side of the cable. The bypass capacitor shall be 10nF ± 20% in cables which incorporate a USB Micro-B plug. The bypass capacitor shall be 100pF ± 20% (minimum voltage rating of 30V) in cables which incorporate a USB PD Micro-B plug. The bypass capacitor should be placed as close as possible to the power supply
pad.
6. All Ground return pins shall be connected together within the USB Type-C plug.
7. Shield and GND grounds shall be connected within the USB Type-C and USB 3.1 Micro-B plugs on both ends of the cable assembly.
8. Pin 4 (ID) of the USB 3.1 Micro-B plug shall be terminated as defined in the applicable specification for the cable type.
9. All USB Type-C plug pins that are not listed in this table shall be open (not connected).

Actual Change Requested

From Text (and location): Section 3.5.7, Table 3-18

Table 3-17 USB Type-C to USB 2.0 Micro-B Cable Assembly Wiring

USB Type-C Plug | Wire | USB 2.0 Micro-B plug
Pin | Signal Name | Wire Number | Signal Name | Pin | Signal Name
A1, B1, A12, B12 | GND | 1 | GND_PWRrt1 | 5 | GND
A4, B4, A9, B9 | VBUS | 2 | PWR_VBUS1 | 1 | VBUS
A5 | CC
B5 | VCONN
A6 | Dp1 | 3 | UTP_Dp | 3 | D+
A7 | Dn1 | 4 | UTP_Dn | 2 | D−
| | | | 4 | ID
Shell | Shield | Braid | Shield | Shell | Shield
Notes:
1. Pin A5 (CC) of the USB Type-C plug shall be connected to GND through a resistor Rd. See Section 4.5.3.2.1 and Table 4-14 for the functional description and value of Rd.
2. Pin B5 (VCONN) of the USB Type-C plug shall be used in electronically marked versions of this cable. See Section 4.9.
3. Contacts B6 and B7 should not be present in the USB Type-C plug.
4. All VBUS pins shall be connected together within the USB Type-C plug. Bypass capacitors are not required for the VBUS pins in this cable.
5. All Ground return pins shall be connected together within the USB Type-C plug.
6. Pin 4 (ID) of the USB 2.0 Micro-B plug shall be terminated as defined in the applicable specification for the cable type.
7. All USB Type-C plug pins that are not listed in this table shall be open (not connected).

To Text (and location): Section 3.5.7, Table 3-18

Table 3-18 USB Type-C to USB 2.0 Micro-B Cable Assembly Wiring

USB Type-C Plug | Wire | USB 2.0 Micro-B plug

Pin | Signal Name | Wire Number | Signal Name | Pin | Signal Name
A1, B1, A12, B12 | GND | 1 | GND_PWRrt1 | 5 | GND
A4, B4, A9, B9 | VBUS | 2 | PWR_VBUS1 | 1 | VBUS
A5 | CC
B5 | VCONN
A6 | Dp1 | 3 | UTP_Dp | 3 | D+
A7 | Dn1 | 4 | UTP_Dn | 2 | D−
| | | | 4 | ID
Shell | Shield | Outer shield | Shield | Shell | Shield

Notes:

1. Pin A5 (CC) of the USB Type-C plug shall be connected to GND through a resistor Rd. See Section 4.5.3.2.1 and Table 4-14 for the functional description and value of Rd.
2. Pin B5 (VCONN) of the USB Type-C plug shall be used in electronically marked versions of this cable. See Section 4.9.
3. Contacts B6 and B7 should not be present in the USB Type-C plug.
4. All VBUS pins shall be connected together within the USB Type-C plug. Bypass capacitors are not required for the VBUS pins in this cable.
5. All Ground return pins shall be connected together within the USB Type-C plug.
6. Shield and GND grounds shall be connected within the USB Type-C and USB 2.0 Micro-B plugs on both ends of the cable assembly.
7. Pin 4 (ID) of the USB 2.0 Micro-B plug shall be terminated as defined in the applicable specification for the cable type.
8. All USB Type-C plug pins that are not listed in this table shall be open (not connected).

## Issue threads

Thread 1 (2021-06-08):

Wire all components together

aynurin, 2021-06-08:
Create wires and connect all peripherals to the mainboard. Make sure all devices respond.

aynurin, 2021-07-08:
Tested all separately. Wiring together doesn't make sense with the current wires and connectors as they are going to be deprecated.

Closed 2021-08-02.

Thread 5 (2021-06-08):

Battery powered

aynurin, 2021-06-08:
The device (mainboard and all peripherals) will be powered by a battery.

The ideal goals are (in the order of priority):

* Fit in the current enclosure (see enclosure design in [assets](https://github.com/aynurin/iot-station/tree/master/assets))
* Able to work in all normal natural environment conditions (humidity 5-95%, temp -40C-+55C)
* Run for a year on a single full charge.
* Able to work under direct sunlight (up to +125C)

Closed 2021-08-02.

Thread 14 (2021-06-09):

Update schematics

aynurin, 2021-06-09:
- [x] Add WROOM power diode
- [x] Add power regulator and rewire CP2102N for self-powered
- [x] Reduce USB power/tx diodes brightness (significantly)

Closed 2021-08-02.

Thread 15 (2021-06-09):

Debug the sleep group

aynurin, 2021-06-09:
The sleep group should allow:
[] Sleep the device on regular intervals
[] Allow the device to prevent it from sleep
[] Figure out if we have to allow external wake up

Closed 2021-07-23.

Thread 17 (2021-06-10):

Look for different wire-to-board connectors

aynurin, 2021-06-10:
The downside of the current connectors is that they are too bulky and difficult to assemble. It feels like we can do a better job in either or both of these areas.

aynurin, 2021-07-10:
Related to #20. Contact the manufacturer for options.

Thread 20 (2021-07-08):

Research wires for wire-to-board connectors

aynurin, 2021-07-08:
The current wires are too stiff and not reliable. It's also way too difficult to assemble a full wire.

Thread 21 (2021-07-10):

Re-engineer the timer block

aynurin, 2021-07-10:
The current timer block is not valid:
1. We don't control the HIGH time of WAKE_UP, but we need to guarantee that M_DRV is pulled to VDD momentarily and not continuously
2. The DRV is Active HIGH, so it should drive the MOSFET as a NOT gate (at the moment it drives it directly)

- [x] See if this timer is necessary or we could use ESP8266 built-in Deep Sleep (think about how to Deep Sleep the peripherals in this case)
- [x] Fix the WAKE_UP logic
- [x] Fix the DRV logic
- [x] Fact check via creating a sequence diagram for ON/OFF states.

Closed 2021-08-02.

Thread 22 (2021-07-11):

Implement a Reset button

aynurin, 2021-07-11:
Maybe it is helpful to easily reboot the board.

Closed 2021-08-02.

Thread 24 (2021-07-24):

Implement battery charging detection

aynurin, 2021-07-24:
CP2102N can report on how much power the charger can take from the USB port as described in section 4.3.4 of the specification. The charging block needs to be configured to take advantage of this detection.

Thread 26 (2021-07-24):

Software sleep

aynurin, 2021-07-24:
Even though the device hardware will disconnect everything on timer, there are cases when the timer keeps running (e.g., when external power source is connected). In this case, the software needs to avoid bombarding the cloud with data.

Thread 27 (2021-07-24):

Soil moisture sensor sensitivity

aynurin, 2021-07-24:
Configure the Soil Moisture Sensor timer with higher sensitivity. Currently, it reads 187 for 100% moist and 226 for dry (at air humidity = 40%). Need to try and adjust the timer and ref. cap. to produce a wider range of values.

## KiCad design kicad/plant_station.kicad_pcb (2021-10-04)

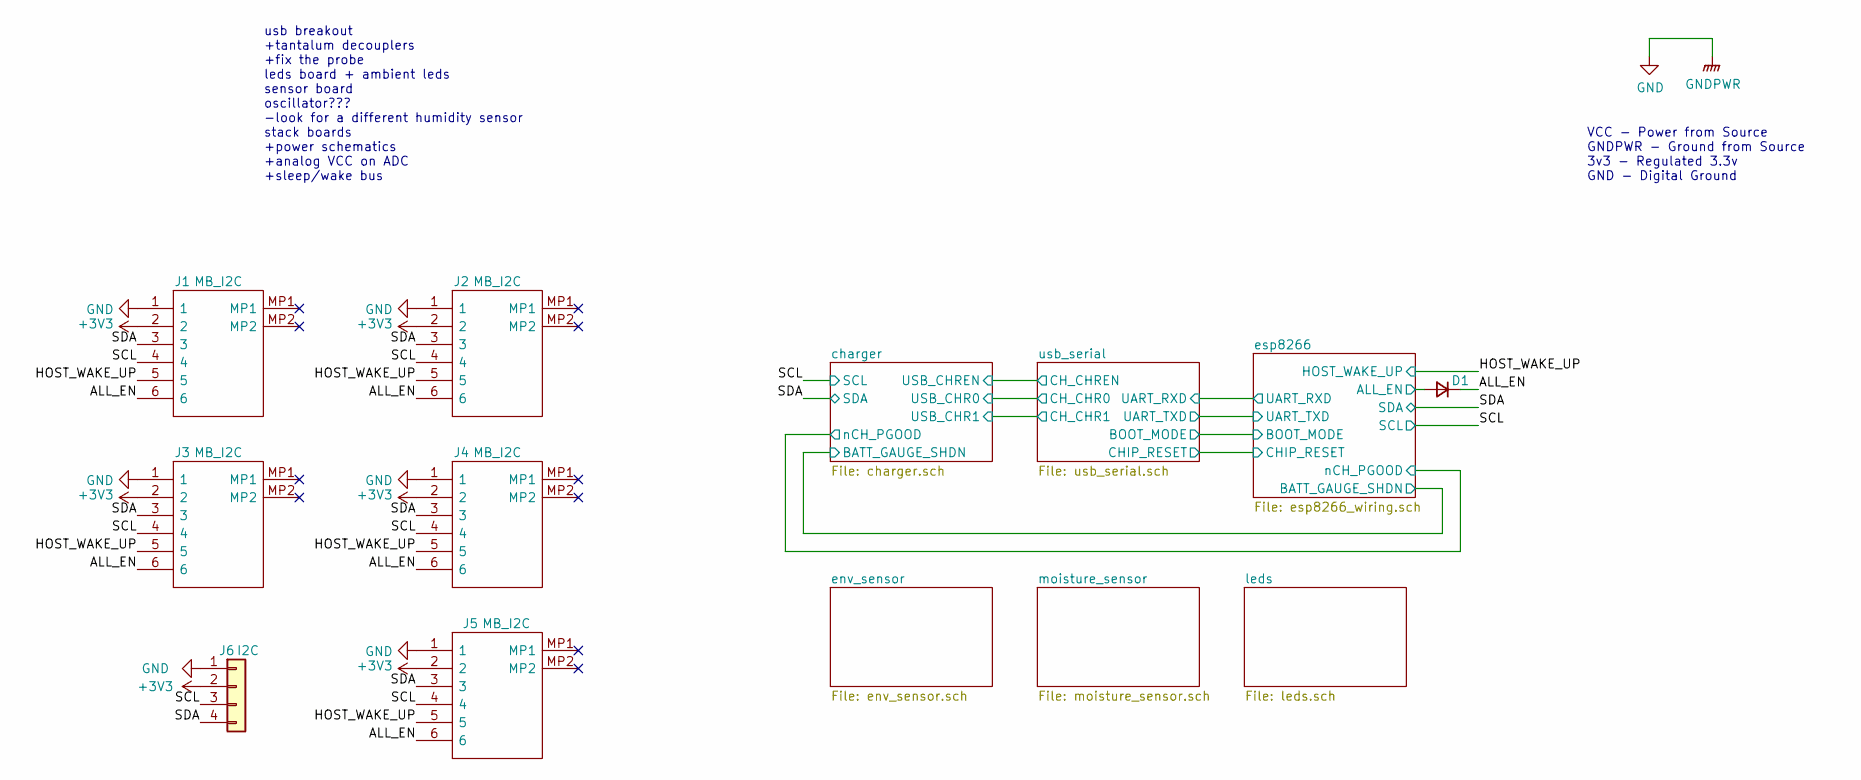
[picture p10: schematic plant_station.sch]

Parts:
D1: LS4148; MELF_SOD_80_3_BZT55B13GS08
J1, J2, J3, J4, J5: MB_I2C; Molex_Conn_SMD_01x06_505567_0671; Manufacturer_Part_Number 505567-0671; Mouser Part Number 538-505567-0671
J6: I2C; PinSocket_1x04_P2.54mm_Vertical

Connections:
/ALL_EN: D1.1 (K), J1.6, J2.6, J3.6, J4.6, J5.6
/HOST_WAKE_UP: J1.5, J2.5, J3.5, J4.5, J5.5; also elsewhere on the board
/SCL: J1.4, J2.4, J3.4, J4.4, J5.4, J6.3; also elsewhere on the board
/SDA: J1.3, J2.3, J3.3, J4.3, J5.3, J6.4; also elsewhere on the board
/esp8266/ALL_EN: D1.2 (A); also elsewhere on the board
GND: J1.1, J2.1, J3.1, J4.1, J5.1, J6.1; also elsewhere on the board

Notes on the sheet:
usb breakout +tantalum decouplers +fix the probe leds board + ambient leds sensor board oscillator??? -look for a different humidity sensor stack boards +power schematics +analog VCC on ADC +sleep/wake bus
VCC - Power from Source GNDPWR - Ground from Source 3v3 - Regulated 3.3v GND - Digital Ground

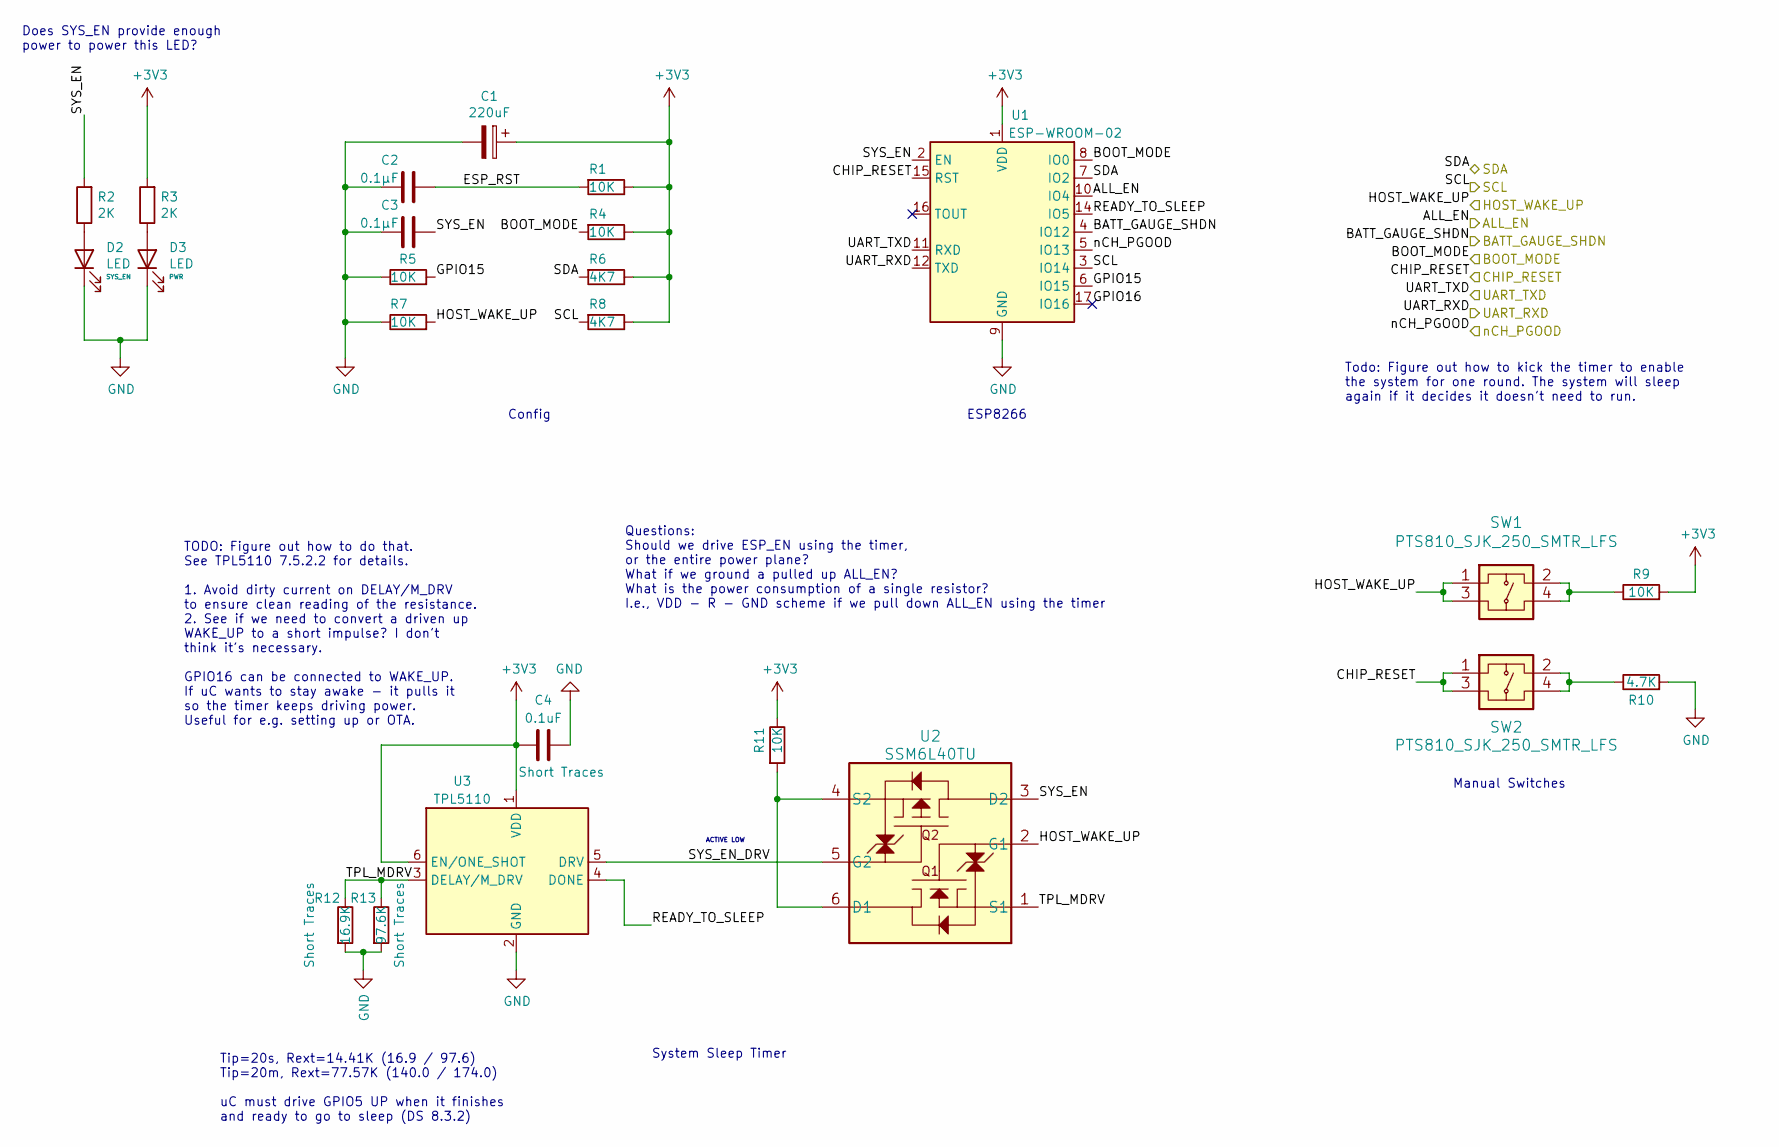
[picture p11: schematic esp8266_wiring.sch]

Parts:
C1: 220uF; CP_EIA-3216-18_Kemet-A
C2, C3: 0.1μF; C_1206_3216Metric
C4: 0.1uF; C_1206_3216Metric
D2, D3: LED; LED_0603_1608Metric
R1, R4, R5, R7, R9, R11: 10K; R_0805_2012Metric
R2, R3: 2K; R_0805_2012Metric
R6, R8: 4K7; R_0805_2012Metric
R10: 4.7K; R_0805_2012Metric
R12: 16.9K; R_0805_2012Metric
R13: 97.6K; R_0805_2012Metric
SW1, SW2: PTS810_SJK_250_SMTR_LFS; PTS810SJK250SMTRLFS
U1: ESP-WROOM-02
U2: SSM6L40TU
U3: TPL5110; SOT-23-6

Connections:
/HOST_WAKE_UP: R7.2, SW1.1, SW1.3, U2.2 (G1); also elsewhere on the board
/SCL: R8.2, U1.3 (IO14); also elsewhere on the board
/SDA: R6.2, U1.7 (IO2); also elsewhere on the board
/charger/BATT_GAUGE_SHDN: U1.4 (IO12); also elsewhere on the board
/charger/nCH_PGOOD: U1.5 (IO13); also elsewhere on the board
/esp8266/ALL_EN: U1.10 (IO4); also elsewhere on the board
/esp8266/BOOT_MODE: R4.2, U1.8 (IO0); also elsewhere on the board
/esp8266/CHIP_RESET: SW2.1, SW2.3, U1.15 (RST); also elsewhere on the board
/esp8266/ESP_RST: C2.2, R1.2
/esp8266/GPIO15: R5.2, U1.6 (IO15)
/esp8266/GPIO16: U1.17 (IO16)
/esp8266/READY_TO_SLEEP: U1.14 (IO5), U3.4 (DONE)
/esp8266/SYS_EN: C3.2, R2.2, U1.2 (EN), U2.3 (D2)
/esp8266/SYS_EN_DRV: U2.5 (G2), U3.5 (DRV)
/esp8266/TPL_MDRV: R12.1, R13.1, U2.1 (S1), U3.3 (DELAY/M_DRV)
/esp8266/UART_RXD: U1.12 (TXD); also elsewhere on the board
/esp8266/UART_TXD: U1.11 (RXD); also elsewhere on the board
GND: C1.2, C2.1, C3.1, C4.1, D2.1 (K), D3.1 (K), R5.1, R7.1, R10.2, R12.2, R13.2, U1.9 (GND), U1.13 (GND), U1.18 (GND), U1.19 (GND), U3.2 (GND); also elsewhere on the board
unnamed: D2.2 (A), R2.1
unnamed: D3.2 (A), R3.1
unnamed: R9.1, SW1.2, SW1.4
unnamed: R10.1, SW2.2, SW2.4
unnamed: R11.2, U2.4 (S2), U2.6 (D1)

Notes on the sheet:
Config
System Sleep Timer
Tip=20s, Rext=14.41K (16.9 / 97.6) Tip=20m, Rext=77.57K (140.0 / 174.0) uC must drive GPIO5 UP when it finishes and ready to go to sleep (DS 8.3.2)
TODO: Figure out how to do that. See TPL5110 7.5.2.2 for details. 1. Avoid dirty current on DELAY/M_DRV to ensure clean reading of the resistance. 2. See if we need to convert a driven up WAKE_UP to a short impulse? I don't think it's necessary. GPIO16 can be connected to WAKE_UP. If uC wants to st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
Questions: Should we drive ESP_EN using the timer, or the entire power plane? What if we ground a pulled up ALL_EN? What is the power consumption of a single resistor? I.e., VDD - R - GND scheme if we pull down ALL_EN using the timer
ACTIVE LOW
ESP8266
Does SYS_EN provide enough power to power this LED?
Manual Switches
Todo: Figure out how to kick the timer to enable the system for one round. The system will sleep again if it decides it doesn't need to run.

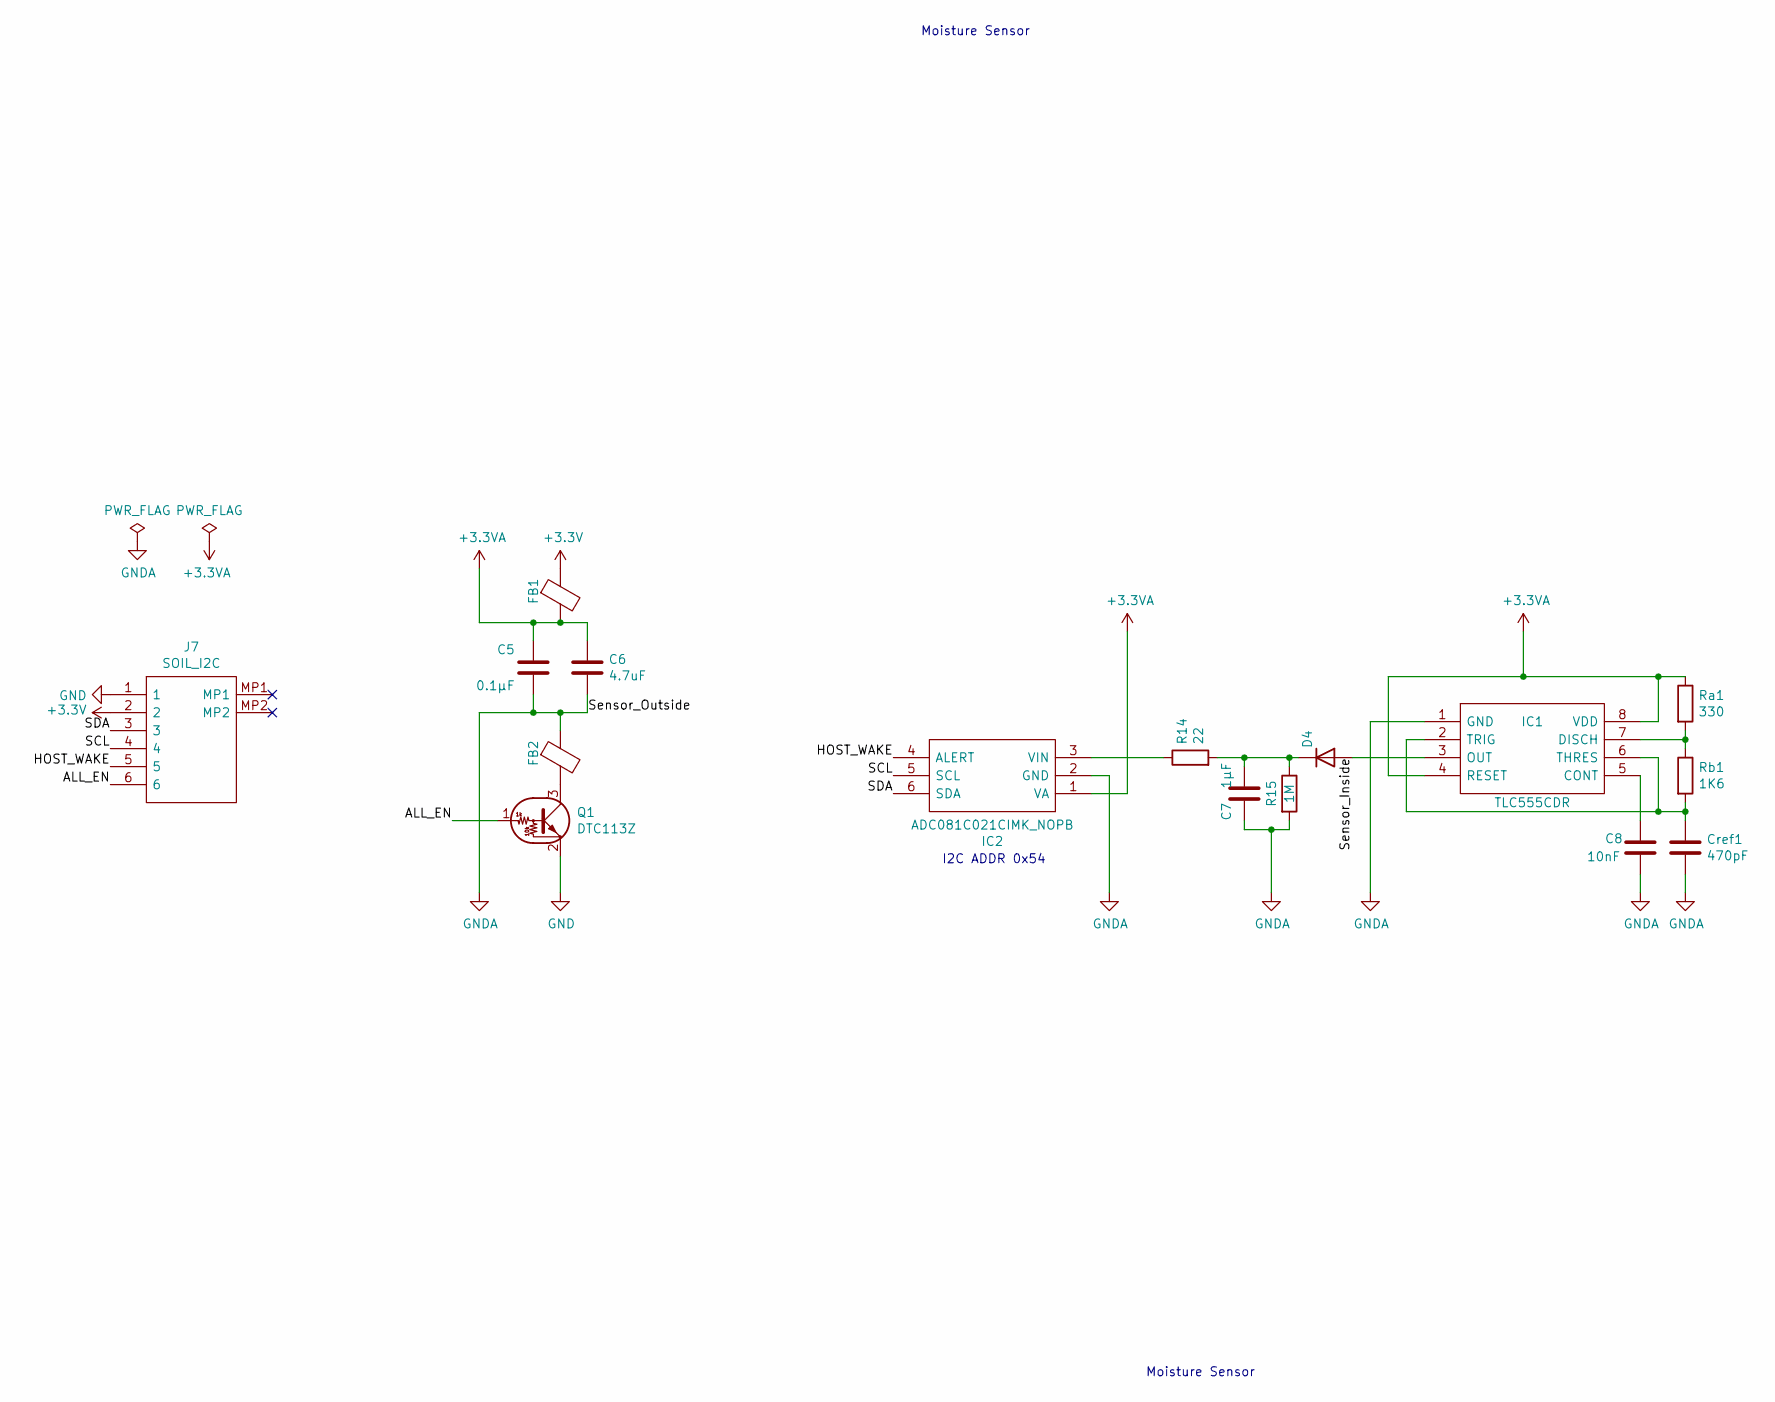
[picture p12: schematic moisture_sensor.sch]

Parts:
C5: 0.1μF; C_1206_3216Metric
C6: 4.7uF; C_1206_3216Metric
C7: 1μF; C_1206_3216Metric
C8: 10nF; C_1206_3216Metric
Cref1: 470pF; C_1206_3216Metric
D4: LS4148; MELF_SOD_80_3_BZT55B13GS08
FB1, FB2: BLM21AG601SZ1D; Ferrite_Bead_0805_BLM21
IC1: TLC555CDR; SOIC127P600X175-8N; Mouser Part Number 595-TLC555CDR
IC2: ADC081C021CIMK_NOPB; SOT95P280X110-6N; Mouser Part Number 926-AD081C021CIMKNPB
J7: SOIL_I2C; Molex_Conn_SMD_01x06_505567_0671; Manufacturer_Part_Number 505567-0671; Mouser Part Number 538-505567-0671
Q1: DTC113Z; DTC113ZEBTL
R14: 22; R_0805_2012Metric
R15: 1M; R_1206_3216Metric
Ra1: 330; R_0805_2012Metric
Rb1: 1K6; R_1206_3216Metric

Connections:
+3.3VA: C5.2, C6.1, FB1.2, IC1.4 (RESET), IC1.8 (VDD), IC2.1 (VA), Ra1.1
/moisture_sensor/ALL_EN: J7.6, Q1.1 (B)
/moisture_sensor/HOST_WAKE: IC2.4 (ALERT), J7.5
/moisture_sensor/SCL: IC2.5 (SCL), J7.4
/moisture_sensor/SDA: IC2.6 (SDA), J7.3
/moisture_sensor/Sensor_Inside: D4.2 (A), IC1.3 (OUT)
GND: J7.1, Q1.2 (E); also elsewhere on the board
GNDA: C5.1, C6.2, C7.2, C8.2, Cref1.2, FB2.1, IC1.1 (GND), IC2.2 (GND), R15.2
unnamed: C7.1, D4.1 (K), R14.2, R15.1
unnamed: C8.1, IC1.5 (CONT)
unnamed: Cref1.1, IC1.2 (TRIG), IC1.6 (THRES), Rb1.2
unnamed: FB2.2, Q1.3 (C)
unnamed: IC1.7 (DISCH), Ra1.2, Rb1.1
unnamed: IC2.3 (VIN), R14.1

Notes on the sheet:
Moisture Sensor
I2C ADDR 0x54

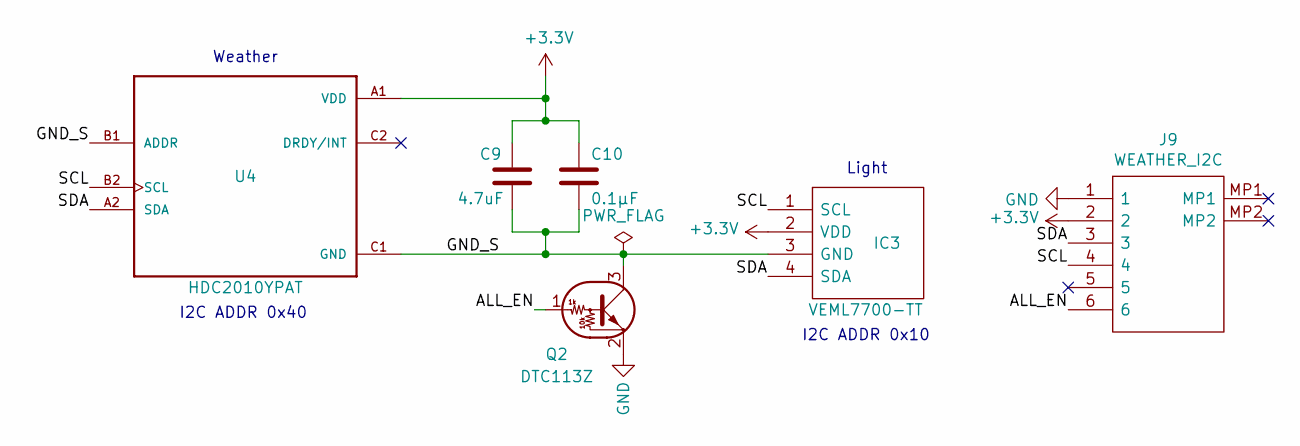
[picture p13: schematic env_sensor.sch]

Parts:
C9: 4.7uF; C_1206_3216Metric
C10: 0.1μF; C_1206_3216Metric
IC3: VEML7700-TT; VEML7700; Mouser Part Number 78-VEML7700-TT
J9: WEATHER_I2C; Molex_Conn_SMD_01x06_505567_0671; Manufacturer_Part_Number 505567-0671; Mouser Part Number 538-505567-0671
Q2: DTC113Z; DTC113ZEBTL
U4: HDC2010YPAT; BGA6C100X50P2X3_146X146X67

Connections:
/env_sensor/ALL_EN: J9.6, Q2.1 (B)
/env_sensor/GND_S: C9.2, C10.2, IC3.3 (GND), Q2.3 (C), U4.B1 (ADDR), U4.C1 (GND)
/env_sensor/SCL: IC3.1 (SCL), J9.4, U4.B2 (SCL)
/env_sensor/SDA: IC3.4 (SDA), J9.3, U4.A2 (SDA)
GND: J9.1, Q2.2 (E); also elsewhere on the board

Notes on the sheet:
Light
I2C ADDR 0x10
Weather
I2C ADDR 0x40

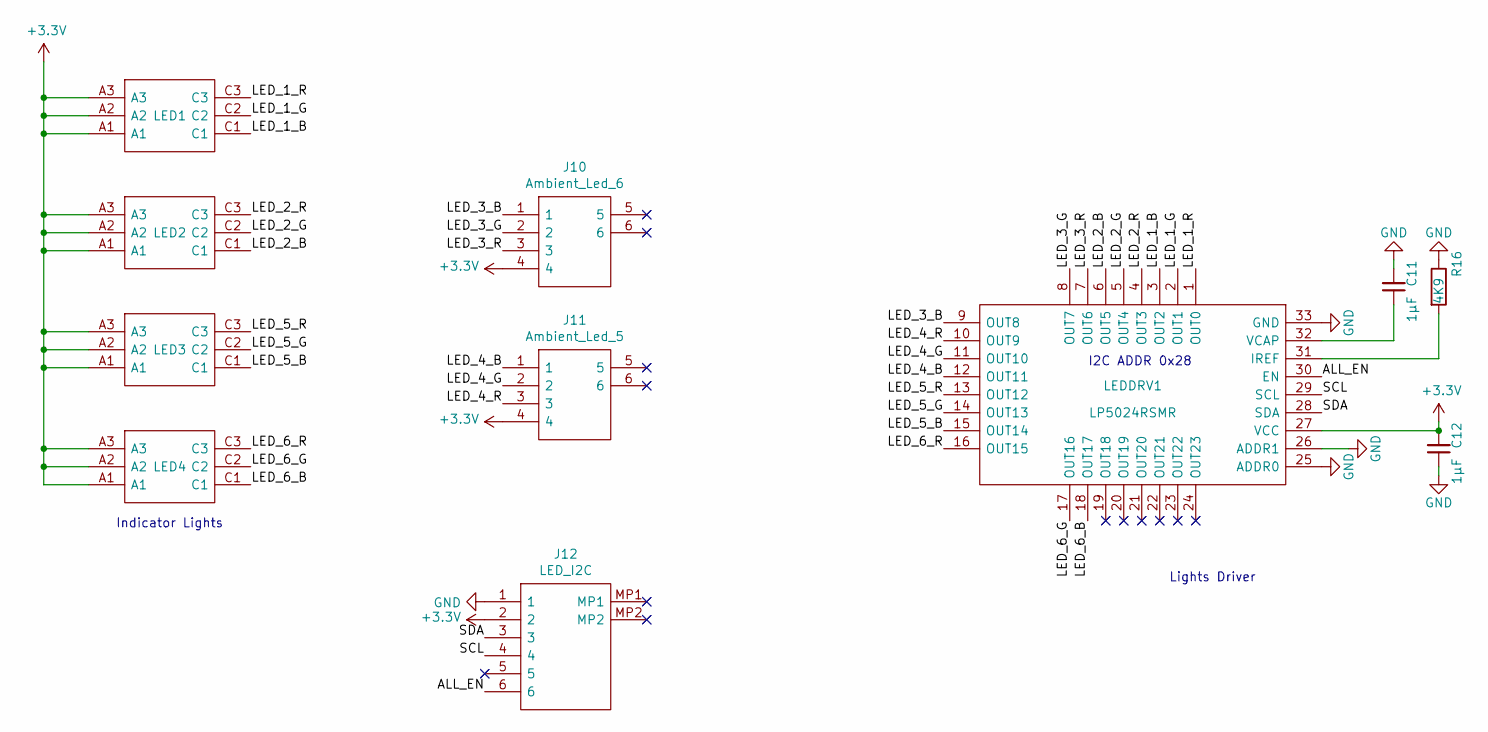
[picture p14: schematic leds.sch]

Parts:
C11, C12: 1μF; C_1206_3216Metric
J10: Ambient_Led_6; Molex_Conn_SMD_01x04_505567_0471; Manufacturer_Part_Number 505567-0471; Mouser Part Number 538-505567-0471
J11: Ambient_Led_5; Molex_Conn_SMD_01x04_505567_0471; Manufacturer_Part_Number 505567-0471; Mouser Part Number 538-505567-0471
J12: LED_I2C; Molex_Conn_SMD_01x06_505567_0671; Manufacturer_Part_Number 505567-0671; Mouser Part Number 538-505567-0671
LED1, LED2, LED3, LED4: KRTBLSLPS1.32-VUVX-EQ+BTBV-D8+TWTZ-L1-B; KRTBLSLPS132VUVXEQBTBVD8TWTZL1B; Mouser Part Number 720-KRTBLSLPS13A0062
LEDDRV1: LP5024RSMR; QFN40P400X400X100-33N-D; Mouser Part Number 595-LP5024RSMR
R16: 4K9; R_0805_2012Metric

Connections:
/leds/ALL_EN: J12.6, LEDDRV1.30 (EN)
/leds/LED_1_B: LED1.C1, LEDDRV1.3 (OUT2)
/leds/LED_1_G: LED1.C2, LEDDRV1.2 (OUT1)
/leds/LED_1_R: LED1.C3, LEDDRV1.1 (OUT0)
/leds/LED_2_B: LED2.C1, LEDDRV1.6 (OUT5)
/leds/LED_2_G: LED2.C2, LEDDRV1.5 (OUT4)
/leds/LED_2_R: LED2.C3, LEDDRV1.4 (OUT3)
/leds/LED_3_B: J10.1, LEDDRV1.9 (OUT8)
/leds/LED_3_G: J10.2, LEDDRV1.8 (OUT7)
/leds/LED_3_R: J10.3, LEDDRV1.7 (OUT6)
/leds/LED_4_B: J11.1, LEDDRV1.12 (OUT11)
/leds/LED_4_G: J11.2, LEDDRV1.11 (OUT10)
/leds/LED_4_R: J11.3, LEDDRV1.10 (OUT9)
/leds/LED_5_B: LED3.C1, LEDDRV1.15 (OUT14)
/leds/LED_5_G: LED3.C2, LEDDRV1.14 (OUT13)
/leds/LED_5_R: LED3.C3, LEDDRV1.13 (OUT12)
/leds/LED_6_B: LED4.C1, LEDDRV1.18 (OUT17)
/leds/LED_6_G: LED4.C2, LEDDRV1.17 (OUT16)
/leds/LED_6_R: LED4.C3, LEDDRV1.16 (OUT15)
/leds/SCL: J12.4, LEDDRV1.29 (SCL)
/leds/SDA: J12.3, LEDDRV1.28 (SDA)
GND: C11.2, C12.1, J12.1, LEDDRV1.25 (ADDR0), LEDDRV1.26 (ADDR1), LEDDRV1.33 (GND), R16.1; also elsewhere on the board
unnamed: C11.1, LEDDRV1.32 (VCAP)
unnamed: LEDDRV1.31 (IREF), R16.2

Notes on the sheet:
Indicator Lights
I2C ADDR 0x28
Lights Driver

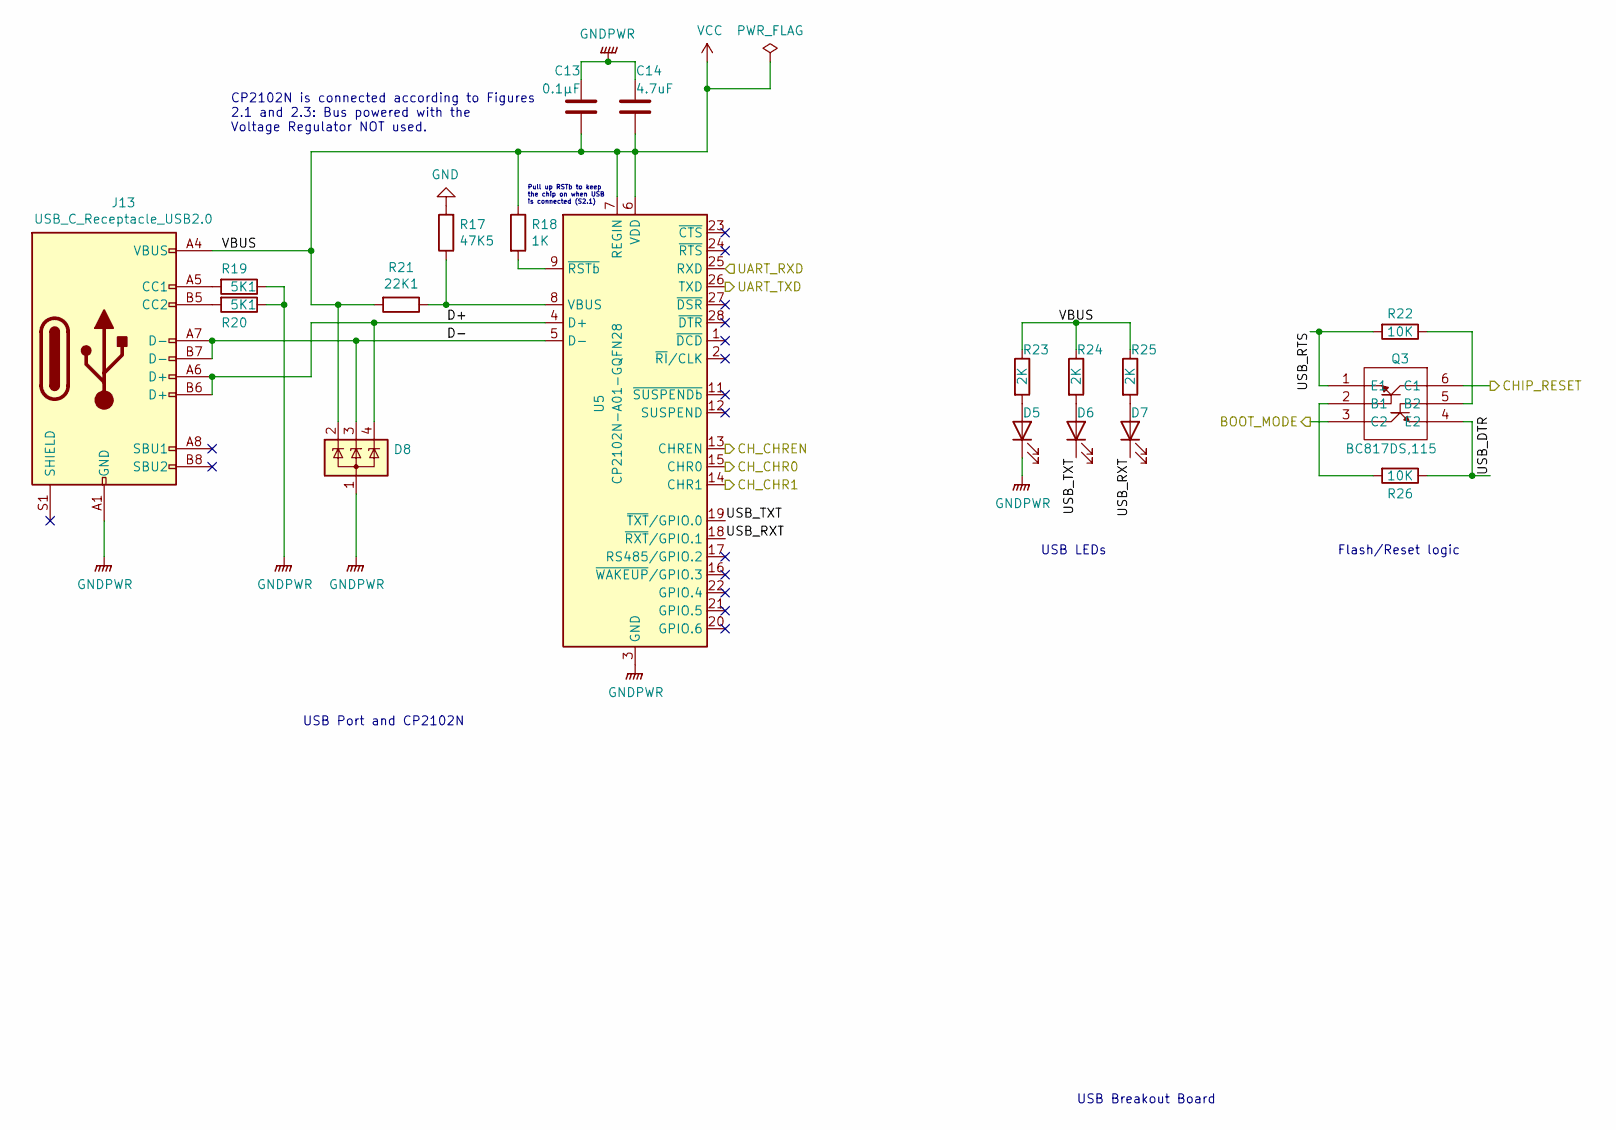
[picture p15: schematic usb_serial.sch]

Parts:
C13: 0.1μF; C_1206_3216Metric
C14: 4.7uF; C_1206_3216Metric
D5: 150060AS75000; LED_0603_1608Metric
D6: 150060BS75020; LED_0603_1608Metric
D7: 150060VS75000; LED_0603_1608Metric
D8: SP0503BAHT; SOT-143
J13: USB_C_Receptacle_USB2.0; CUI_UJ31-CH-3-SMT-TR
Q3: BC817DS,115; SOT95P275X110-6N; Manufacturer_Part_Number BC817DS,115; Mouser Part Number 771-BC817DS115
R17: 47K5; R_0805_2012Metric
R18: 1K; R_0805_2012Metric
R19, R20: 5K1; R_0805_2012Metric
R21: 22K1; R_0805_2012Metric
R22, R26: 10K; R_0805_2012Metric
R23, R24, R25: 2K; R_0805_2012Metric
U5: CP2102N-A01-GQFN28; QFN-28-1EP_5x5mm_P0.5mm_EP3.35x3.35mm

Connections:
/esp8266/BOOT_MODE: Q3.3 (C2); also elsewhere on the board
/esp8266/CHIP_RESET: Q3.6 (C1); also elsewhere on the board
/esp8266/UART_RXD: U5.25 (RXD); also elsewhere on the board
/esp8266/UART_TXD: U5.26 (TXD); also elsewhere on the board
/usb_serial/CH_CHR0: U5.15 (CHR0); also elsewhere on the board
/usb_serial/CH_CHR1: U5.14 (CHR1); also elsewhere on the board
/usb_serial/CH_CHREN: U5.13 (CHREN); also elsewhere on the board
/usb_serial/D+: D8.4 (K), J13.A6 (D+), J13.B6 (D+), U5.4 (D+)
/usb_serial/D-: D8.3 (K), J13.A7 (D-), J13.B7 (D-), U5.5 (D-)
/usb_serial/USB_DTR: Q3.4 (E2), R26.1
/usb_serial/USB_RTS: Q3.1 (E1), R22.2
/usb_serial/USB_RXT: D7.1 (K), U5.18 (~RXT~/GPIO.1)
/usb_serial/USB_TXT: D6.1 (K), U5.19 (~TXT~/GPIO.0)
GND: C13.2, C14.1, D5.1 (K), D8.1 (A), J13.A1 (GND), J13.A12 (GND), J13.B1 (GND), J13.B12 (GND), R17.2, R19.1, R20.1, U5.3 (GND), U5.29 (GND); also elsewhere on the board
unnamed: D5.2 (A), R23.2
unnamed: D6.2 (A), R24.2
unnamed: D7.2 (A), R25.2
unnamed: J13.A5 (CC1), R19.2
unnamed: J13.B5 (CC2), R20.2
unnamed: Q3.2 (B1), R26.2
unnamed: Q3.5 (B2), R22.1
unnamed: R17.1, R21.1, U5.8 (VBUS)
unnamed: R18.2, U5.9 (~RSTb)
VCC: C13.1, C14.2, D8.2 (K), J13.A4 (VBUS), J13.A9 (VBUS), J13.B4 (VBUS), J13.B9 (VBUS), R18.1, R21.2, R23.1, R24.1, R25.1, U5.6 (VDD), U5.7 (REGIN); also elsewhere on the board

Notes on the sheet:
USB Breakout Board
USB LEDs
Pull up RSTb to keep the chip on when USB is connected (S2.1)
CP2102N is connected according to Figures 2.1 and 2.3: Bus powered with the Voltage Regulator NOT used.
Flash/Reset logic
USB Port and CP2102N

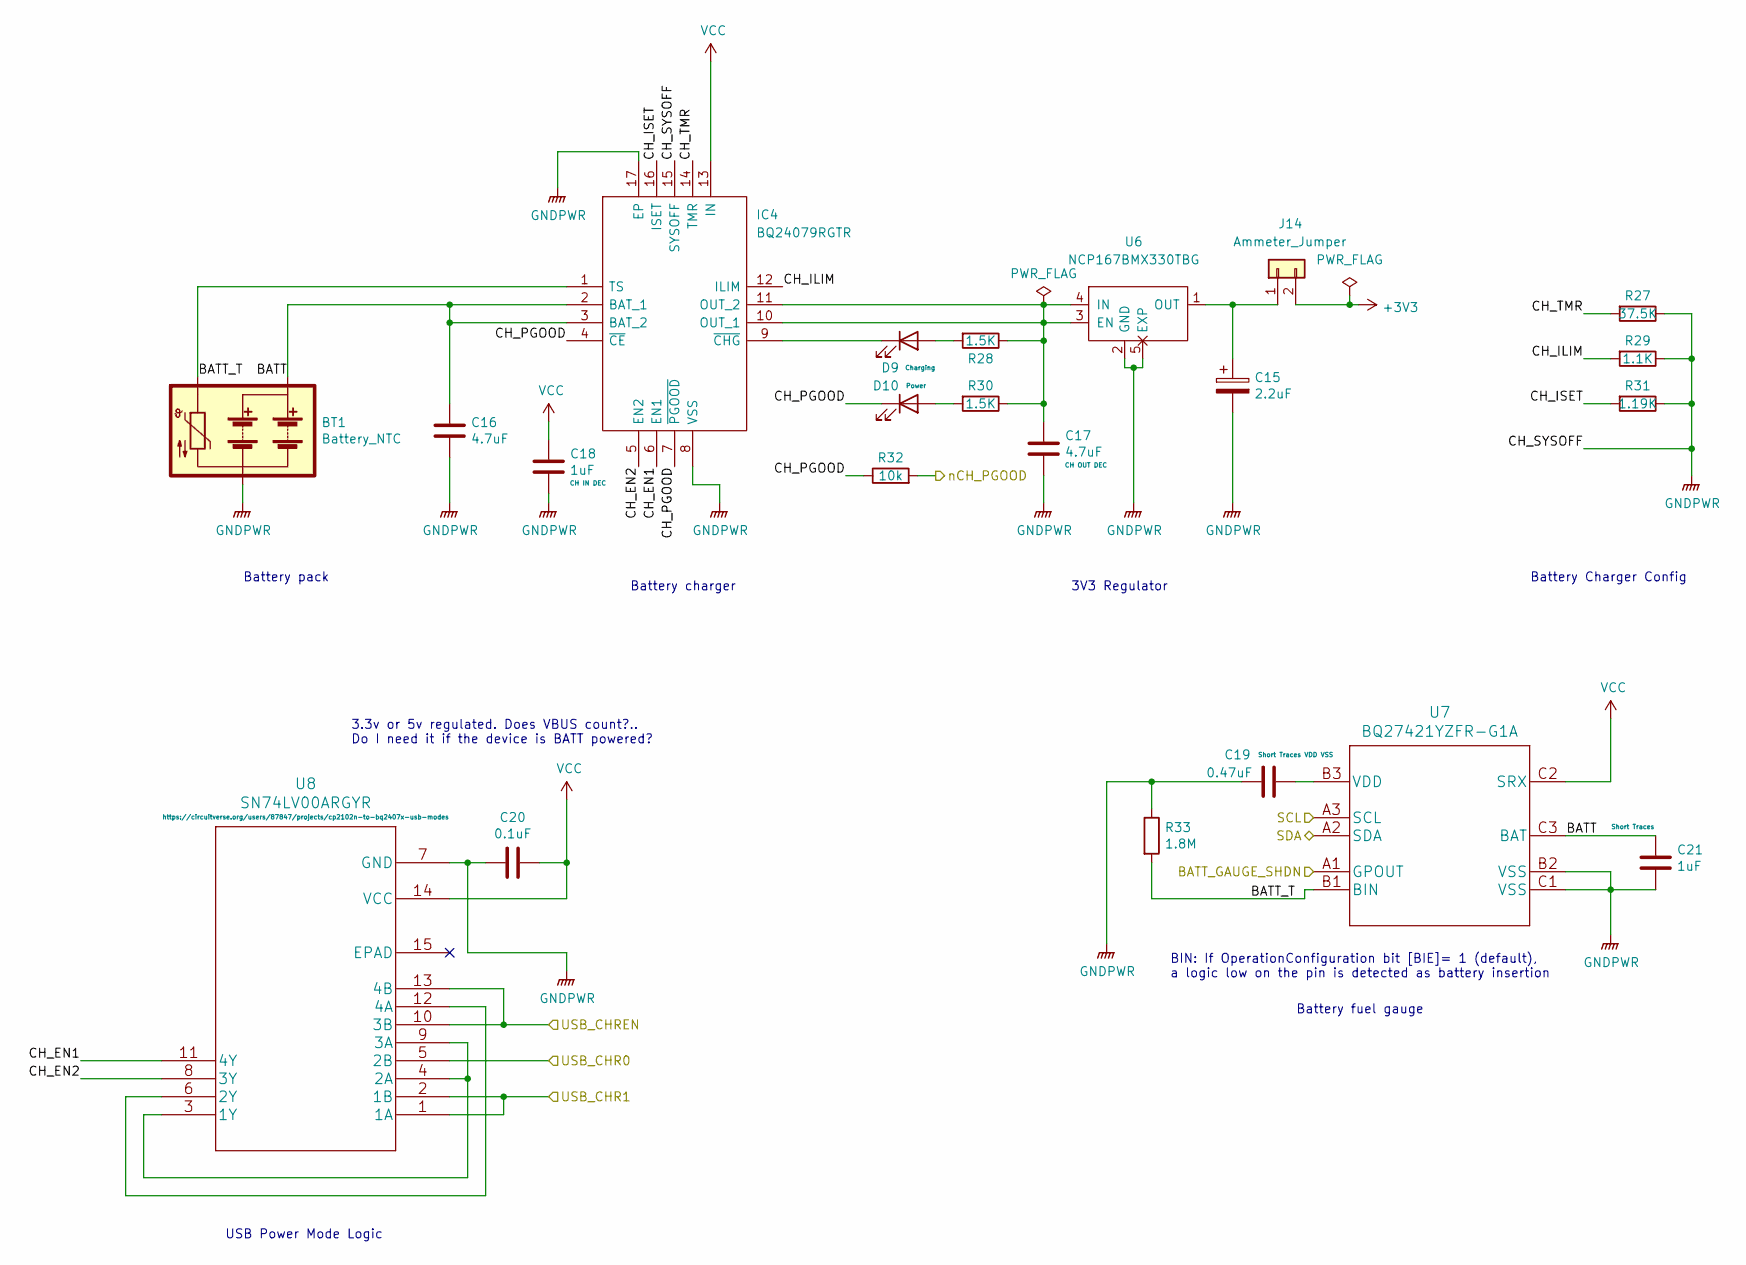
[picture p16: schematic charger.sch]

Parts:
BT1: Battery_NTC; JST_EH_B3B-EH-A_1x03_P2.50mm_Vertical
C15: 2.2uF; C_1206_3216Metric
C16, C17: 4.7uF; C_1206_3216Metric
C18, C21: 1uF; C_1206_3216Metric
C19: 0.47uF; C_1206_3216Metric
C20: 0.1uF; C_1206_3216Metric
D9, D10: LED; LED_0603_1608Metric
IC4: BQ24079RGTR; QFN50P300X300X100-17N-D; Manufacturer_Part_Number BQ24079RGTR; Mouser Part Number 595-BQ24079RGTR
J14: Ammeter_Jumper; PinHeader_1x02_P2.54mm_Vertical
R27: 37.5K; R_0805_2012Metric
R28, R30: 1.5K; R_0805_2012Metric
R29: 1.1K; R_0805_2012Metric
R31: 1.19K; R_0805_2012Metric
R32: 10k; R_0805_2012Metric
R33: 1.8M; R_0805_2012Metric
U6: NCP167BMX330TBG; REG_NCP167BMX330TBG
U7: BQ27421YZFR-G1A
U8: SN74LV00ARGYR

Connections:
/SCL: U7.A3 (SCL); also elsewhere on the board
/SDA: U7.A2 (SDA); also elsewhere on the board
/charger/BATT: BT1.3 (+), C16.1, C21.1, IC4.2 (BAT_1), IC4.3 (BAT_2), U7.C3 (BAT)
/charger/BATT_GAUGE_SHDN: U7.A1 (GPOUT); also elsewhere on the board
/charger/BATT_T: BT1.2 (TH_NTC), IC4.1 (TS), R33.2, U7.B1 (BIN)
/charger/CH_EN1: IC4.6 (EN1), U8.11 (4Y)
/charger/CH_EN2: IC4.5 (EN2), U8.8 (3Y)
/charger/CH_ILIM: IC4.12 (ILIM), R29.2
/charger/CH_ISET: IC4.16 (ISET), R31.2
/charger/CH_PGOOD: D10.1 (K), IC4.4 (~CE), IC4.7 (~PGOOD), R32.1
/charger/CH_TMR: IC4.14 (TMR), R27.2
/charger/nCH_PGOOD: R32.2; also elsewhere on the board
/usb_serial/CH_CHR0: U8.5 (2B); also elsewhere on the board
/usb_serial/CH_CHR1: U8.1 (1A), U8.2 (1B); also elsewhere on the board
/usb_serial/CH_CHREN: U8.10 (3B), U8.13 (4B); also elsewhere on the board
GND: BT1.1 (-), C15.2, C16.2, C17.2, C18.1, C19.2, C20.2, C21.2, IC4.8 (VSS), IC4.15 (SYSOFF), IC4.17 (EP), R27.1, R29.1, R31.1, R33.1, U6.2 (GND), U6.5 (EXP), U7.B2 (VSS), U7.C1 (VSS), U8.7 (GND); also elsewhere on the board
unnamed: C15.1, J14.1, U6.1 (OUT)
unnamed: C17.1, IC4.10 (OUT_1), IC4.11 (OUT_2), R28.1, R30.1, U6.3 (EN), U6.4 (IN)
unnamed: C19.1, U7.B3 (VDD)
unnamed: D9.1 (K), IC4.9 (~CHG)
unnamed: D9.2 (A), R28.2
unnamed: D10.2 (A), R30.2
unnamed: U8.3 (1Y), U8.4 (2A), U8.9 (3A)
unnamed: U8.6 (2Y), U8.12 (4A)
VCC: C18.2, C20.1, IC4.13 (IN), U7.C2 (SRX), U8.14 (VCC); also elsewhere on the board

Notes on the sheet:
Battery fuel gauge
Battery pack
3.3v or 5v regulated. Does VBUS count?.. Do I need it if the device is BATT powered?
3V3 Regulator
BIN: If OperationConfiguration bit [BIE]= 1 (default), a logic low on the pin is detected as battery insertion
Battery charger
USB Power Mode Logic
Battery Charger Config

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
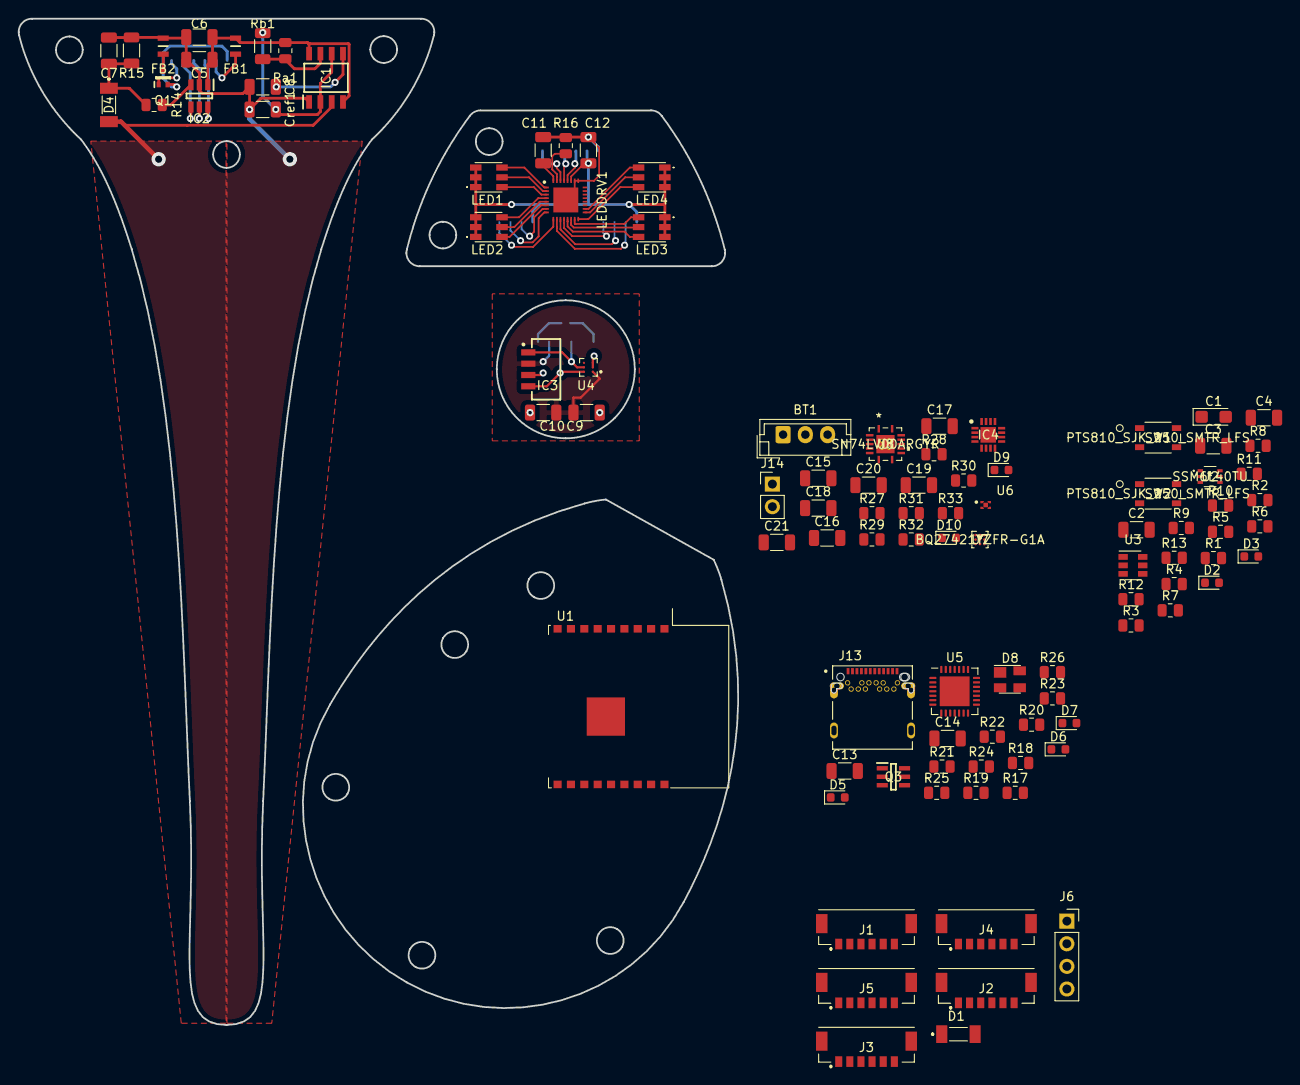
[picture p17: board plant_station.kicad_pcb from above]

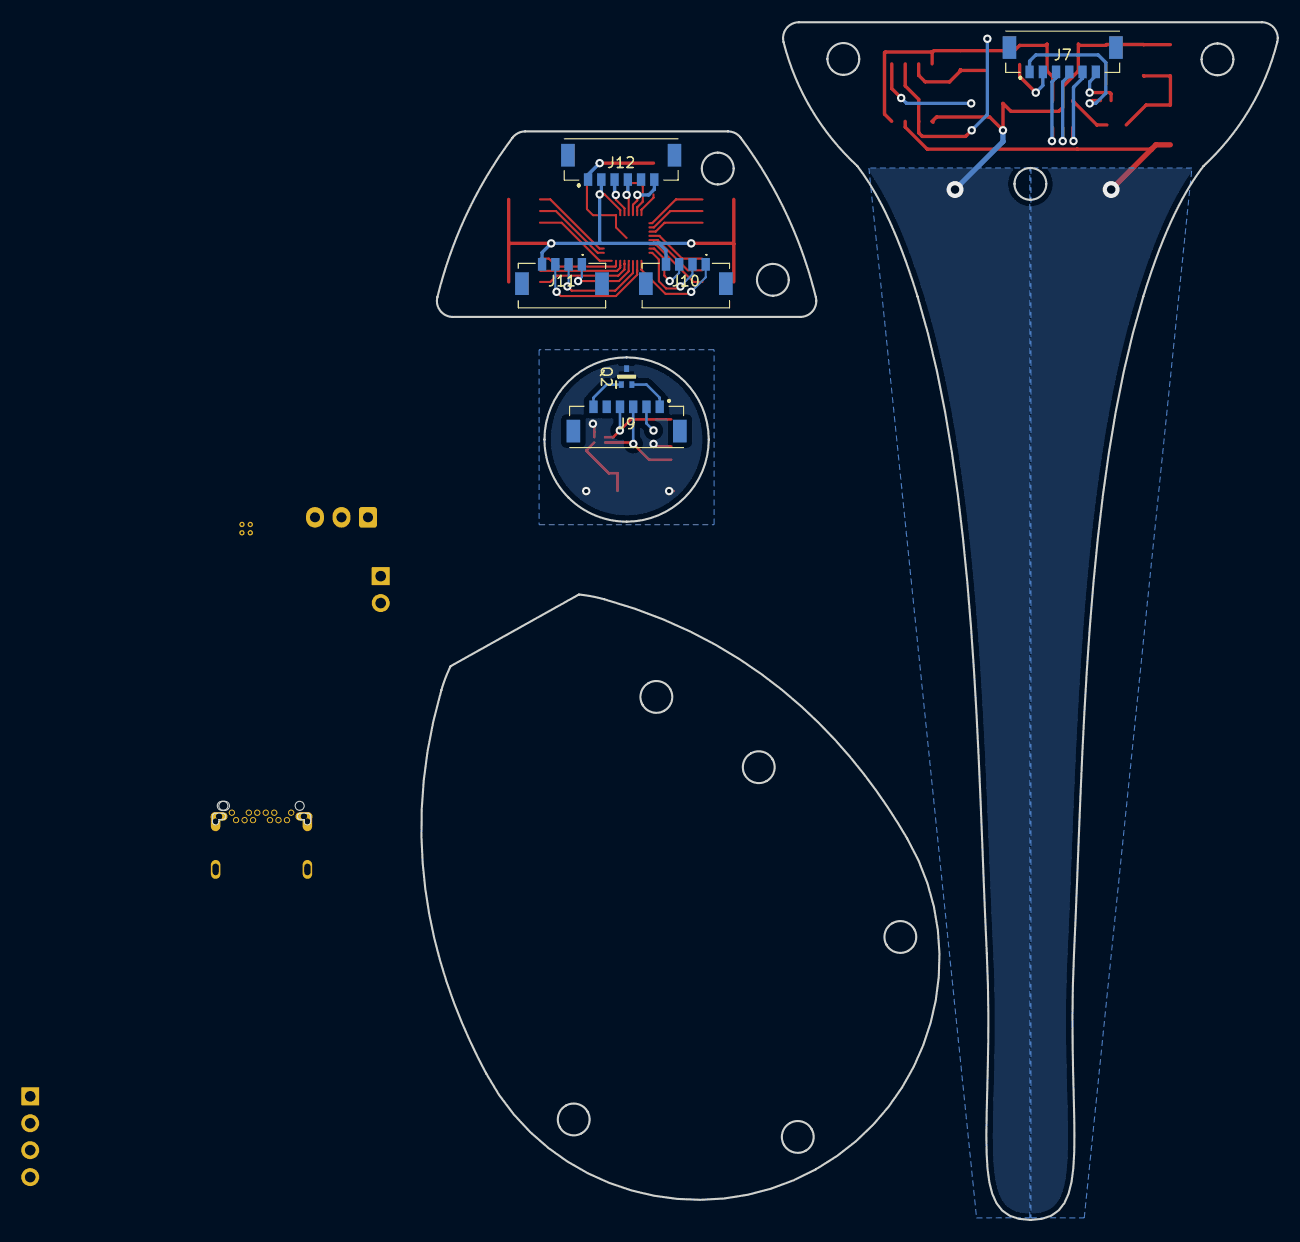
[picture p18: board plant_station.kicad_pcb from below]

Board: 2 copper layers, 100.5 x 113.0 mm, 105 parts (6 on the bottom side), 99 nets.

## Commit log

2020-05-23 CCS811 wired and reading
2020-06-04 Remapped I2C pins to D3 and D1 to release a PWM pin
2020-06-07 Soil moisture sensor
2020-06-15 KiCad draft
    [draft.kicad_pcb, draft.sch]
2020-06-16 Added GND and 3V3 areas and tracks to connect NodeMCU
    [draft.kicad_pcb, draft.sch]
2020-06-19 PCB 0.1 sent to production
    [draft-B_Cu.gbr, draft-B_Mask.gbr, draft-B_Paste.gbr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]
2020-07-03 Scheme v.2 wired up
    [Adafruit STEMMA Soil Sensor.brd, Adafruit STEMMA Soil Sensor.sch, CAP1293-1-AC3-TR.stp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]
2020-07-10 Board v.2 sent for printing
    [HDC2010YPAT--3DModel-STEP-56544.STEP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]
2020-07-28 Started working on v3 - added ADC081 driver and removed CAP and IQS chips
    [esp8266_wiring.sch, moisture_sensor.sch, plant_station_v2.kicad_pcb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]
2020-08-12 v3 schematics complete, USB breakout PCB designed
    [env_sensor.sch, esp8266_wiring.sch, leds.sch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]
2020-08-12 v3 PCB in progress. Need to move LED driver to LEDs board and make it connect using the standard interface
    [env_sensor.sch, leds.sch]
2020-08-13 Moved the LED driver to LEDs board, refactored connectors. Hopefuly PCBNEW could update it all in place
    [env_sensor.sch, esp8266_wiring.sch, leds.sch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]
2020-08-14 LEDs board done via I2C bus
    [leds.sch, plant_station_v3.kicad_pcb]
2020-08-18 Initial board layout complete
    [board_edge_cuts.dxf, board_shape.dxf, esp8266_wiring.sch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]
2020-08-30 pcb v3 sent to production and the first attempts to design the enclosure
    [enclosure.blend, enclosure2.blend, enclosure_freecad.FCStd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]
2021-07-11 Pre-refactoring, diagnostics complete, timer not working properly
    [enclosure-bottom.stl, enclosure-top.stl, enclosure_freecad.FCStd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]
2021-07-24 project folder cleanup
    [505567-0471.stp, 505567-0671.stp, 5055670471.stp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]
2021-07-24 USB Wiring updated to fix RSTb pull-up
    [usb_serial.sch]
2021-07-24 Added USB Charger Detection Specification (BCv1.2_070312)
2021-07-25 SPX3819 resistance calculator
2021-07-30 Libraries cleanup
    [505567-0471.stp, 505567-0671.stp, 5055670471.stp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]
2021-08-01 Charger initial wiring complete
    [charger.sch, esp8266_wiring.sch, usb_serial.sch]
2021-08-01 Schematics cleanup
    [charger.sch, esp8266_wiring.sch, plant_station.sch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]
2021-08-02 Comitting yesterday's leftovers
    [charger.sch, env_sensor.sch, esp8266_wiring.sch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]
2021-08-03 Relabeled and completed ERC
    [charger.sch, esp8266_wiring.sch, leds.sch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]
2021-10-04 Mapped footprints, PCB in progress
    [board_edge_cuts.dxf, board_shape.dxf, charger.sch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]

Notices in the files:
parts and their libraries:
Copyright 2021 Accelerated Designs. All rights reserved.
